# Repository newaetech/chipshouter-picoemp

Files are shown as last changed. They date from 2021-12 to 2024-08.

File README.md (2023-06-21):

# ChipSHOUTER-PicoEMP

[][cc-by-sa]

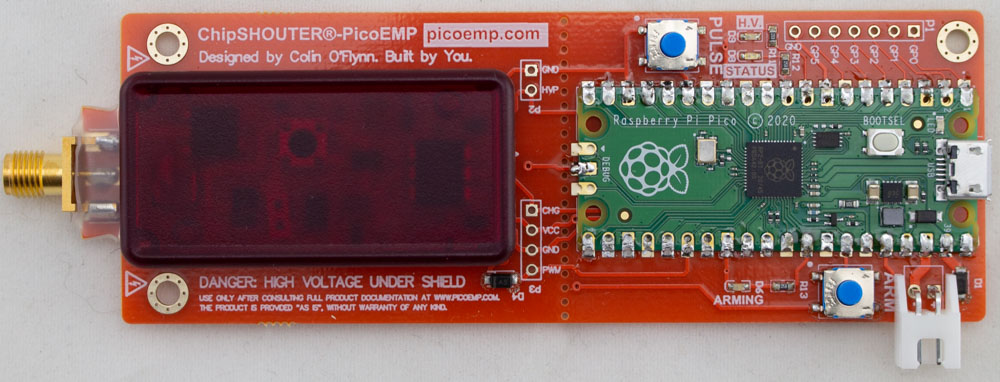
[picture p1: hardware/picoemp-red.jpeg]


The PicoEMP is a low-cost Electromagnetic Fault Injection (EMFI) tool, designed *specifically* for self-study and hobbiest research. Under the safety shield it looks like this:

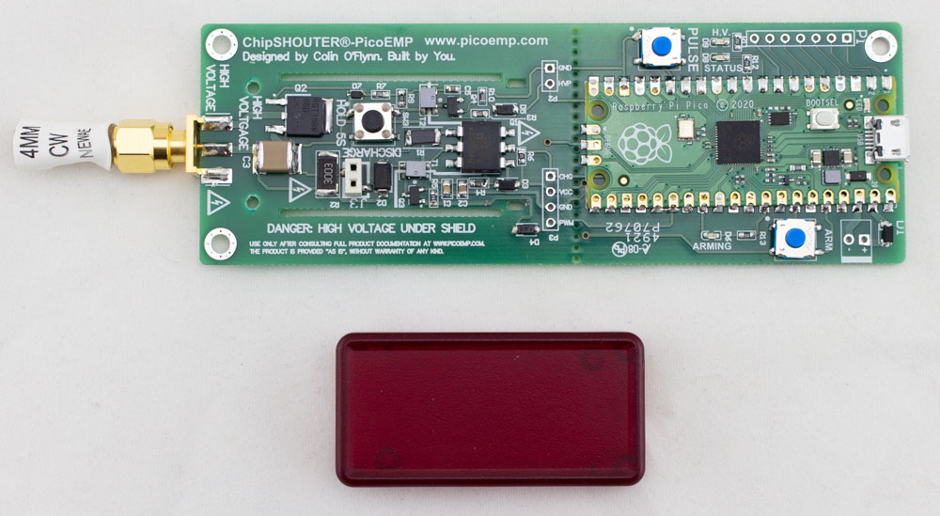
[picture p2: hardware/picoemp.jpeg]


You can see some details of the design in the [Intro Video](https://www.youtube.com/watch?v=nB5arJi-tVE).

## Thanks / Contributors

PicoEMP is a community-focused project, with major contributions from:
* Colin O'Flynn (original HW design, simple Python demo)
* [stacksmashing](https://twitter.com/ghidraninja) (C firmware for full PIO feature-set)
* [Lennert Wouters](https://twitter.com/LennertWo) (C improvements, first real demo)
* [@nilswiersma](https://github.com/nilswiersma) (Triggering/C improvements)

## Background

The [ChipSHOUTER](http://www.chipshouter.com) is a high-end Electromagnetic Fault Injection (EMFI) tool designed by Colin
at [NewAE Technology](http://www.newae.com). While not the first commercially available EMFI tool, ChipSHOUTER was the first
"easily purchasable" (even if expensive) tool with extensive open documentation. The tool was *not* open-source, but it
did contain a variety of detailed description of the design and architecture in the
[User Manual](https://github.com/newaetech/ChipSHOUTER/tree/master/documentation). The ChipSHOUTER design optimization focused in rough order on (1) safe operation, (2) high performance, (3) usability, and finally (4) cost. This results in a tool that covers many use-cases, but may be overkill (and too costly) for many. In additional, acquiring the safety testing/certification is not cheap, and must be accounted for in the product sale price.

The PicoEMP tries to fill in the gap that ChipSHOUTER leaves at the lower end of the spectrum. This PicoEMP project is *not* the
ChipSHOUTER. Instead it's designed to present a "bare bones" tool that has a design optimization focused in rough order of (1) safe
operation, (2) cost, (3) usability, (4) performance. Despite the focus on safety and low-cost, it works *suprisingly* well. It is also
*not* sold as a complete product - you are responsible for building it, ensuring it meets any relevant safety requirements/certifications,
and we completely disclaim all liability for what happens next. Please **only** use PicoEMP where you are building and controlling it
yourself, with total understanding of the operation and risks. It is *not* designed to be used in professional or educational environments,
where tools are expected to meet safety certifications (ChipSHOUTER was designed for these use-cases).

As an open-source project it also collects inputs from various community members, and welcomes your contributions! It also has various remixes of it, including:

* TODO link to people's remixes.

## Building a PicoEMP

The PicoEMP uses a Raspberry Pi Pico as the controller, inspired by @nezza using it for the debug-n-dump tool. You could alternatively use an Arduino or another microcontroller. You basically just need a few things:

1. PWM output to drive HV transformer.
2. Pulse pin to generate a pulse.
3. Status pin to monitor the HV status.

You have two options for building the PicoEMP: (1) total scratch build, or (2) easy-assemble build.

### Scratch Build

The PCB is *mostly* one layer. Original versions of it were milled on a Bantam PCB mill, and the final 'production' version is designed
to still allow this simple milling process. You can find details in the [gerbers](hardware/gerbers) folder, including Bantam-optimized files
which remove some of the smaller vias (used for the mounting holes), and require you to surface-mount the Raspberry Pi Pico. Here was
'rev3' of the PCB with a few hacked up tests:

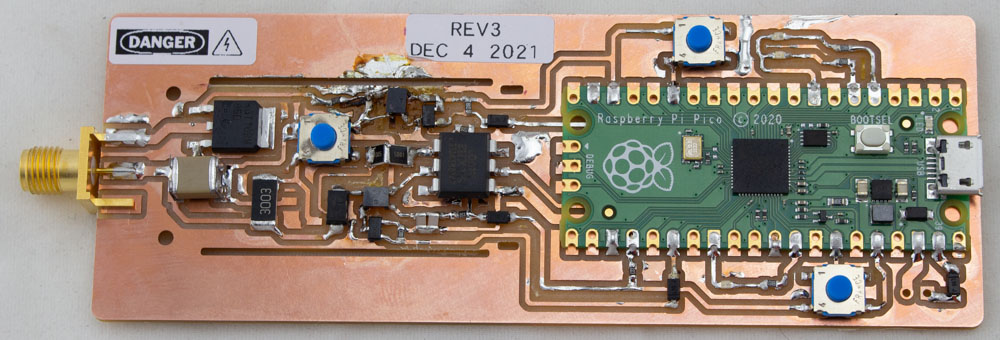
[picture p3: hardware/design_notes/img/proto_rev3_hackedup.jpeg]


If you've got time you can order the "real" PCBs from the [gerbers](hardware/gerbers) as well.

The BOM and build details are described in the [hardware](hardware) folder. If you cannot find the plastic shield (the upper half of Hammond
1551BTRD is used), you can find a simple 3D-printable shield as well. The official shield is low-cost and available from Digikey/Mouser/
Newark so you can purchase alongside everything else you need.

**IMPORTANT**: The plastic shield is critical for safe operation. While the output itself is isolated from the input connections, you will still **easily shock yourself** on the exposed high-voltage capacitor and circuitry. **NEVER** operate the device without the shield.

### Easy-Assemble Build

The Easy-Assembly build uses a "mostly complete" SMD board, which you need to solder a Raspberry Pi Pico, switches, and through-hole headers. Currently it's available only on the [NewAE Store](https://store.newae.com/chipshouter-picoemp). We're working to
get this listed on Mouser for much cheaper worldwide shipping (the NewAE store doesn't get great rates & due to issues with Canada's postal system for international shipments quotes mostly via DHL).

### Programming the PicoEMP

You'll need to program the PicoEMP with the firmware in the [firmware](firmware) directory. You can run other tasks on the microcontroller
as well.

### Building the EM Injection Tip (Probe / Coil)

You will also need an "injection tip", typically made with a ferrite core and some wires wrapped around it. You can see examples of such cores in the ChipSHOUTER kit. The following shows a few homemade & commercial tips:

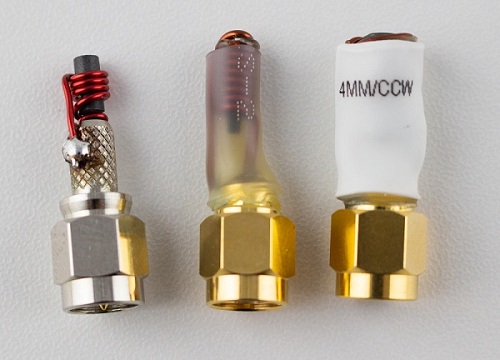
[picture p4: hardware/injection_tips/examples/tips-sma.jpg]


You can make your own from suitable SMA connectors, magnet wire, and a ferrite core material. See the [injection_tips](hardware/injection_tips)
folder for more examples and details on building the probes.

*Reader Note: Please submit your own examples with a pull-request to this repo, it would be great to have more examples of probe geometries*

You can find additional examples of homemade cores in research papers such as:

* A. Cui, R. Housley, "BADFET: Defeating Modern Secure Boot Using Second-Order Pulsed Electromagnetic Fault Injection," USENIX Workshop on Offensive Technologies (WOOT 17), 2017.  [Paper Link.](https://www.usenix.org/conference/woot17/workshop-program/presentation/cui) [Slides Link.](https://github.com/RedBalloonShenanigans/BADFET)
* J. Balasch, D. Arumí and S. Manich, "Design and validation of a platform for electromagnetic fault injection," 2017 32nd Conference on Design of Circuits and Integrated Systems (DCIS), 2017, pp. 1-6. [Paper Link.](https://upcommons.upc.edu/bitstream/handle/2117/116688/bare_conf.pdf)
* J. Toulemont, G. Chancel, J. M. Galliere, F. Mailly, P. Nouet and P. Maurine, "On the scaling of EMFI probes," 2021 Workshop on Fault Detection and Tolerance in Cryptography (FDTC), 2021. [Paper Link.](https://ieeexplore.ieee.org/abstract/document/9565575) [Slides Link.](https://jaif.io/2021/media/JAIF2021%20-%20Toulemont.pdf)
* LimitedResults. "Enter the Gecko," 2021. [Blog Link](https://limitedresults.com/2021/06/enter-the-efm32-gecko/)
* C. Gaine, J-P. Nikolovski, D. Aboulkassimi, J-M. Dutertre. "New probe design for hardware characterization by ElectroMagnetic Fault Injection," EMC Europe 2022 [Paper Link.] (https://hal-cea.archives-ouvertes.fr/cea-03657852/file/article_archivesouvertes.pdf)
* 
### Useful References

If you don't know where to start with FI, you may find a couple chapters of the [Hardware Hacking Handbook](https://nostarch.com/hardwarehacking) useful.

You can see a demo of PicoEMP being used on a real attack in this [TI CC SimpleLink attack demo](https://github.com/KULeuven-COSIC/SimpleLink-FI/blob/main/notebooks/5_ChipSHOUTER-PicoEMP.ipynb).

## Using the PicoEMP

The general usage of the PicoEMP is as follows:

1. Press the "ARM" button. The red "ARMING" led will come on instantly telling you it's trying to charge the high voltage.
2. The red "HV" led will come on after a few seconds saying it is charged to "some voltage".
3. Place the probe tip overtop of the target.
4. Press the "Pulse" button.

You can see more examples of this in the [Intro Video](https://www.youtube.com/watch?v=nB5arJi-tVE).

You can even use the Raspberry Pi Pico to attack a Raspberry Pi "regular"! Here's a demo hitting a RSA signature on a Raspberry Pi (the demo code taken from Colin's [Remoticon 2021 Talk](https://github.com/colinoflynn/remoticon-2021-levelup-hardware-hacking/tree/master/rpi-glitching)):

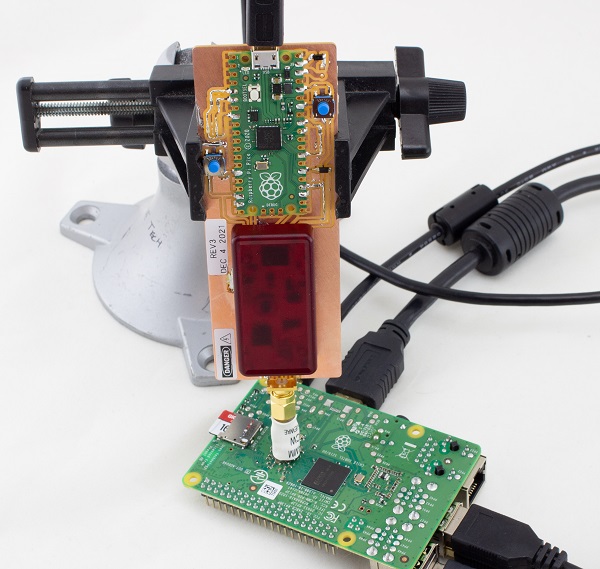
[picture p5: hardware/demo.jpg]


**WARNING**: The high voltage will be applied across the SMA connector. If an injection tip (coil) is present, it will absorb most of the power. If you leave the SMA connector open, you will present a high voltage pulse across this SMA and could shock yourself. Do NOT touch the output SMA tip as a general "best practice", and treat the output as if it has a high voltage present.

The full ChipSHOUTER detects the missing connector tip and refuses to power up the high voltage, the PicoEMP does not have this failsafe!

## About the High Voltage Isolation

Most EMFI tools generate high voltages (similar to a camera flash). Many previous designs of open-source EMFI tools would work well, but [exposed the user to high voltages](https://github.com/RedBalloonShenanigans/BADFET). This was fine provided you use the tool correctly, but of course there is always a risk of grabbing the electrically "hot" tool! This common design choice happens because the easiest way to design an EMFI tool is with "low-side switching" (there is a very short mention of these design choices as well in my [book](https://www.nostarch.com/hardwarehacking) if you are curious). With low-side switching the output connector is always "hot", which presents a serious shock hazard.

PicoEMP gets around this problem by floating the high-voltage side, meaning there is no electrical path between the EMFI probe output and the input voltage ground. With the isolated high voltage output we can use the simple "low-side switching" in a safe manner. Some current will still flow due to the high-frequency spikes, so this isn't *perfect*, but it works well enough in practice (well enough you will shock yourself less often).

The caveat here is for this to work you also need to isolate your gate drive. There are a variety of [solutions to this](https://www.analog.com/en/technical-articles/powering-the-isolated-side-of-your-half-bridge-configuration.html), with the simplist being a gate drive transformer (GDT). The PicoEMP uses the transformer architecture, with some simplifications to further reduce BOM count.

More details of the design are available in the [hardware](hardware) folder.

### Hipot Testing for Validating Isolation

Easy-assemble builds have been subject to a hipot test. This test validates the isolation exists, and has not been compromised by things like leftover flux on the PCB.

This test applies a high voltage (1000V) from the SMA connector pads to the low-voltage signals shorted together. The test is done at 1000V DC, with test passing if LESS than 1 uA of current flows over the 60 seconds test duration. Note this limits is *far* lower than most industry standard limits.

### Technical Differences between ChipSHOUTER and PicoEMP

The main differences from a technical standpoint:

* ChipSHOUTER uses a much more powerful high voltage circuit and transformer (up to ~30W vs ~0.2W) that gives it
  almost unlimited glitch delivery, typically limited by your probe tip. The PicoEMP is slower to recover, typically ~1 to 4 seconds between
  glitches.

* ChipSHOUTER has a larger internal energy storage & more powerful output drivers.

* ChipSHOUTER has a controlled high-voltage setting from 150V to 500V. PicoEMP generates ~250V, there is some feedback but it's uncalibrated.
  **NOTE**: The PicoEMP allows some control of output pulse size by instead controlling the drive signal. This is less reliable (more variability
  in the output), but meets the goal of using the lowest-cost control method.

## License

This work is licensed under a [Creative Commons Attribution-ShareAlike 3.0 International License][cc-by-sa].

[cc-by-sa]: http://creativecommons.org/licenses/by-sa/3.0/
[cc-by-sa-image]: https://licensebuttons.net/l/by-sa/3.0/88x31.png
[cc-by-sa-shield]: https://img.shields.io/badge/License-CC%20BY--SA%203.0-lightgrey.svg

ChipSHOUTER is a trademark of NewAE Technology Inc., registered in the US, European Union, and other jurisdictions.
PicoEMP is a trademark of NewAE Technology Inc.

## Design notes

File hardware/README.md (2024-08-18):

# PicoEMP Build Details

*This page is a (continous) work in progress, original design files in Altium are uploaded*

## BOM

Due to the horribleness that is the 2021 Supply Chain Issues, this "bom explainer" is included and
is split into several parts.
This helps you find alternate parts that you will require because the part we used originally is
not available anywhere.

Part numbers are given in this format (which can be uploaded to e.g., Digi-Key)
```
QUANTITY,PART NUMBER,REF DES
```

Be sure to pick up all parts in the following **4** subsections:

### BOM PART 1: Specific Parts

The following parts are fairly specific and very hard to sub and core to the design:

```
2,ATB322524-0110-T000,T1 T2
1,MM3Z18VB,D7
1,LDA111STR,Q1
1,1551BTRD,SHIELD
1,SC0915,U1
```

NOTES:
* If you can't find ATB322524 basically all is lost. Some distributors just use the `ATB322524` part
number instead of the full one given above, so try the shorter number on Octopart or similar.
* If you can't find MM3Z18VB (D7) try another Zener in ~15V to 20V range. But this diode drastically
affects the drive waveform, so try to avoid subing it.
* The opto LDA111STR is very low-current, and other ones are less likely to work with
the circuit as-is. The feedback isn't "required" per-say so you can omit that circuitry.
* If you can't find `1551BTRD` a 3D printed solution is available, but it will be about
50% less cool-looking.

If you somehow can't get the RPi Pico all is not lost - the pin headers on the board can be driven
with the required signals. If you have another RP2040 board this should be easy, but you could even
drive the signals from an Arduino or similar.

### BOM PART 2: Slightly Generic Parts

The following parts are a little generic, but you try to get the suggested ones if in stock:

```
1,RGT16BM65DTL,Q2
2,AO3422,Q3 Q4
1,TL3301AF160QJ,SW3
1,MURA160T3G,D2
4,SM4005PL-TP,D1 D3 D4 D5
1,KRM55TR72J474MH01K,C3
1,CRMA2010AF20M0FKEF,R1
1,3522300KFT,R2
1,BG306-02-A-2-0400-L-G,J3
1,0732511150,J1
```

KNOWN SUBS:
* D2: US1J-13-F (tested by @gashtaan in [#36](https://github.com/newaetech/chipshouter-picoemp/issues/36), now used in some builds)
* Q3/Q4: PMV37ENEAR
* J1: 142-0701-801

NOTES:
* Q2 is IGBT, 500V+ rating in TO-252 ('DPAK'). Watch a sub here as gate charge may be different which will affect drive
  waveform. In theory you can use a MOSFET instead too (pinout "should" be compatable).
* Q3/Q4 are logic level N-Channel MOSFETs, I use higher voltage rating ones due to potential for inductive kick.
  Watch the gate turn-on voltage, don't just rely on "logic level". Sub a lower Vds rating FET if required.
  *WARNING*: These MOSFETs seem to be surprisingly hard to source sometimes.
* SW3 is a 'discharge' switch and is optional, it should be 5mm high to provide clearance.
* J3 is optional (used for calibrating charge voltage, not used normally).
* D1 D3 D4 D5 are HV diodes for isolation. Suggested ones have 600V rating which is only used in case iolation
breakdown occurs. In circuit they will be exposed to 4V max ever. Almost any diode can be sub'd OK. (NB: The schematic
& old versions of this doc claimed they were Schottky diodes, but as @settinger caught this was never the case).
* C3 is 630V rated, 0.47uF capacitor. Can sub anything in ~0.1uF to 1uF range with same voltage rating & case size
  (watch height! Must be below 5mm to fit shield).
* R1 is 20M-ohm, 2010 size. 1% to 5% is all OK, this part isn't very specific. At least 100mW rating, ideally
  at least 500V rating. Probably will need to change value if you change Q1 (or due to variation of Q1).
* R2 is 300K-ohm, 2510 size. Any value in 120K to 470K is fine. Rated part is 3W which is way overkill, anything 1/4W
  or higher is fine. Dissipation only occurs when you press discharge button.
* J1 is Edge mount SMA. You can sub another connector here or anything else you want (such as screw terminals).

### BOM PART 3: Very Generic Parts

The following parts are not very specific to the design, and you may be better off selecting parts available
at the time. For some of our builds we used existing stock we had that fit the requirements, so there is no
"validated/preferred" part number (unlike Part 1 & Part 2).

```
2,KSC741J LFS,SW1 SW2
2,10R 0603 RESISTOR,R3 R7
1,75R 0805 RESISTOR,R4
5,1K 0603 RESISTOR,R5 R10 R11 R12 R13
1,2K 0805 RESISTOR,R9
1,22K 0603 RESISTOR,R6
2,4.7uF 50V 0805 CERAMIC CAPACITOR,C1 C2
1,100nF 0603 CERAMIC CAPACITOR,C5
2,APT1608SRCPRV,D6 D9
1,APT1608CGCK,D8
```

NOTES:
* SW1 SW2: You can use the same PN as SW3 (the footprint is the same). The suggested switches are kinda
  squishy which I like the feel of more. If you are mounting R-Pi Pico with pins you probably want higher
  switches (like SW3).
* Resistors were 1% in test builds due to our stock, but values not critical. 5% tol is fine.
* C1/C2 were 50V in test builds (50V rating shared with parts from BasicBBI). PicoEMP does not need
  such high rating, but still suggest 25V or higher to avoid biasing voltage reducing effective capacitance.
* C5 was a 50V cap in test builds, but anything > 16V should be fine.
* LEDs: These are just some part numbers we used for one build, but in practice any 0603 red/green LED
  should work.
* You can use 0603 resistors in place of 0805. All prototype builds were done with 0603 to no ill effect.

### BOM PART 4: Other Useful Parts

In practice it's handy having the battery input, which is designed to use the following:

```
1,S2B-XH-A(LF)(SN),J2
1,PRT-09925,BATTERY HOLDER
```

PRT-09925 is a Sparkfun AA battery holder with power switch, terminated in 2.5mm (0.1") JST-XH connector.
This goes right to the R-Pi Pico power input, see the R-Pi Pico documentation for allowed input voltage
ranges.

You will also want some SMA connectors & ferrites to actually use your tool! So pick up for example
at least the following for a minimal-fuss option:
```
1,CONSMA013.062
1,PCV-0-472-03L
1,744710603
```

The SMA connector is to mate with the SMA on the output. You might want to pickup several of them.

Finally you should pick up a USB isolator if you plan on communicating with this thing in operation. There
are lots of these available, but one tested part number you can order from Digi-Key:
```
Seeed Technology Co 114991949
```

Alternatively try `Adafruit 2107`.

### Minimum Build

If you run into supply chain issues, the *absolute minimum parts* needed are:

* Shield (Hammond 1551BTRD)
* T1, T2 (Transformers)
* D2 (High Voltage Rectifier)
* Q2 (High Voltage Switch)
* Q3, Q4 (Low voltage logic-level MOSFET)
* C1, C2 (Caps on HV transformer)
* C3 (Cap on gate drive transformer)
* R3--R7, R9--R13 (various 0603 & 0805 resistors)
* D1, D3--D5 (generic schottky diodes) - they can be replaced with jumpers.
* D7 is *highly recommended* but technically optional, you may immediatly blow up Q2 without it.

This minimum build dumps some features (such as 'charge OK' feedback) and may require more
tuning.

## PCBs

The PCB gerbers can be found in the [gerbers](gerbers) folder. There are two versions:

* Regular Version
* Bantam Mill Version

### Regular Version

The regular gerbers have very little special about them. They should be accepted by your fav
PCB fab (OSHPark, JLCPCB, PCBWay, AllPCB, Advanced Circuits, etc).

The board can be hand-built if you have done a few SMD builds before. The smallest parts are 0603
so there is nothing very crazy. Watch the build order on some parts to make soldering easier:

* Mount J3 (if using) before the nearby SMD parts.
* Mount SW1 & SW2 after mounting R-Pi Pico if SMD mounting the R-Pi Pico.
* Mount Q1 (6-pin optoisolator) after parts around it.

### Bantam Version

The 'bantam mill version' is optimized for milling on a Bantam PCB mill, but could be done with
a classic PCB etch or other PCB mill. It removes most of the throuh-holes from the NC-Drill file
and only includes the copper layers.

This file should work well using both the `0.005" PCB Engraving Bit` and `1/32 end mill` combination.

See the [gerbers/rev04_bantam/README.md](gerbers/rev04_bantam/README.md) file which annotates using this & the required jumper wire!

## Build Process

### PCBA

A assembly drawing is available in the file [BUILD-DRAWING-REV04.PDF](BUILD-DRAWING-REV04.PDF)
which includes the location of parts. Lines indicate the cathods of diodes. The angled ends of
the LEDs indicates their cathods. Some specific notes:

* Watch transformer T1 and T2 have a dot that needs to be matched to the assembly drawing/silkscreen.

* Q1 (6-pin optoisolator) has pin 1 marked on the silkscreen with a line above pin 1 - check this carefully.
  See the photo of assembled boards for a better reference.

* Check D7 cathod carefully - if mounted backwards (or there is an open solder joint on it) you may
  blow up Q2 (the large MOSFET). Depending on your equipment on-hand Q2 may be difficult to replace.

### Shields

The safety shield should "just fit" if the PCB was made correctly with the milled out slots. Use
#2 screws to fit the safety shield - you can cut the ones provided with the Hammond Enclosure in
half with a large pair of side cutters. If your shield doesn't fit, you can use the "other side"
of the Hammond Enclosure (which doesn't have the protrusions) and simply hot glue it to the PCB.

A piece of heat shrink will fit over the connector J1 to ensure only one "pin" is exposed. The
pyramid-like flare on J1 is designed to help the heatshrink fit snugly onto J1.

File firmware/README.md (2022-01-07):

# Firmware

This directory includes the firmware loaded onto the Raspberry Pi Pico.

## C

The C firmware in the [c](c) directory was started by @nezza, and is the most robust/future-proof firmware option!
This includes a serial console similar to ChipSHOUTER, and also allows usage of an external
trigger input.

## Micropython

The micropython firmware is a basic Micropython example. See the [micropython](micropython)
directory for that version and instructions on loading.

This firmware allows only manual usage by the button, and does not include a serial console.

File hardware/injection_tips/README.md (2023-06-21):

# Building Injection Tips

The injection tips are a key part of the usage
of your EMFi tool. This page includes some
examples and tips for when you go to build
your EM tip.

Typically the design of the tips is wire wrapped
around a ferrite core. The core helps
concentrate the magnetic field, up to a factor 2/3, but isn't
required to be present.

## Ferrite Cores

Ferrite cores can be purchased off the shelf
from electronics distributors. You can often
search for "rods" for example. Fair-Rite types 78 and 61 ferrites are well suited and a reference for fault injection. The ferrite diameter is also ideal because it can vary from 750µm to several mm. 

### Shaping Ferrite Cores

Ferrite cores can be shaped with a wet grinding
wheel. These are typically used as knife
sharpeners. The following example one was
purchased from Busy Bee Tools in Canada 
(similar to Harbour Freight in US), part number
CT191:

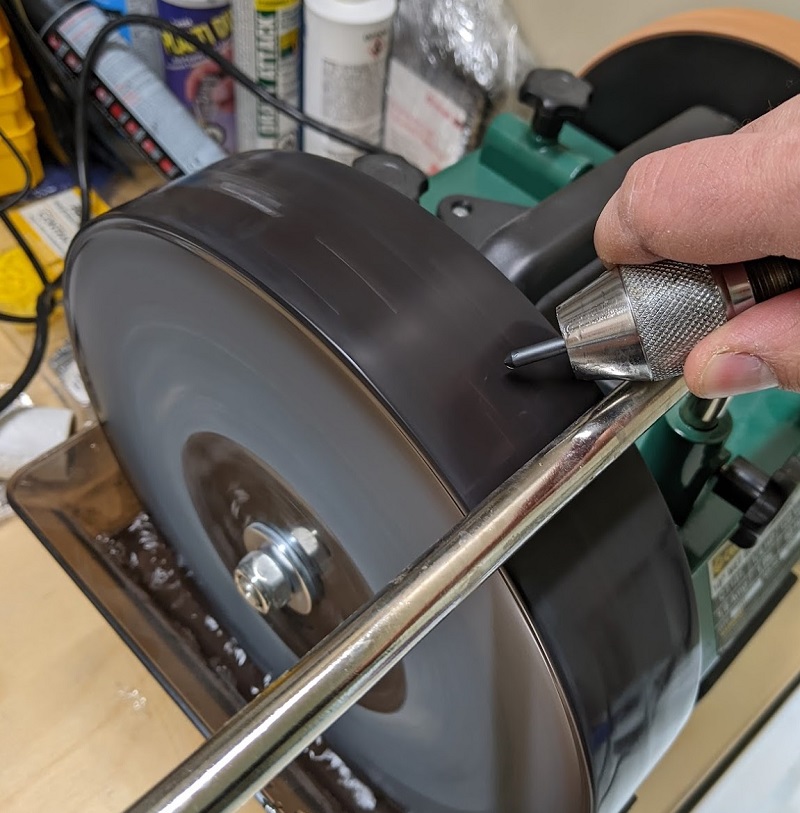
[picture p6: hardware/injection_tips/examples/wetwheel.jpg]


This can be especially useful for shortening
cores. To do this:

1. Cut or break the core with pliers.
2. Use the wet wheel to flaten off the broken end.

## SMA Adapters

Various SMA connectors can be used to adapt to
the SMA connector. For example:

* CONSMA013.062 is used in several examples below. It's an edge-mount male connector.

## Various Examples

### Built Using Inductors

Ferrite-core inductors are common parts, and save you from winding your own coils.

#### Coil Craft

The following was built using `PCV-0-472-03L` inductor. This ferrite has a 'hollow core', but
still seems effective for F-I purposes:

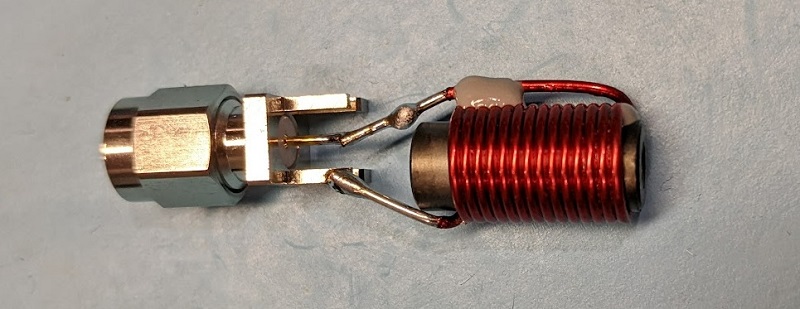
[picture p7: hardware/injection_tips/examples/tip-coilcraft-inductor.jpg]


#### Würth Elektronik

The following is a smaller inductor, Wurth `744710603` (available on Digi-Key):

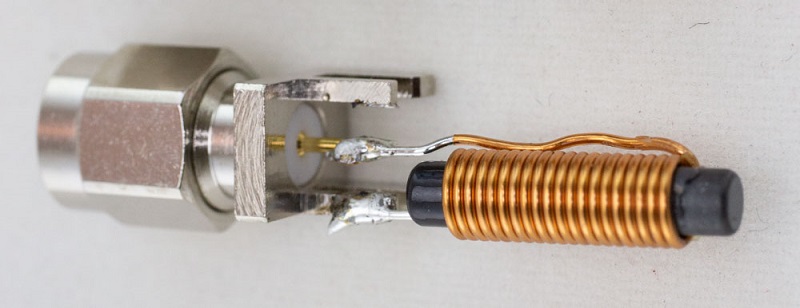
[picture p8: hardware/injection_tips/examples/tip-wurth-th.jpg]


You need to unwind a wrapping to connect to the SMA. I'd consider trying this coil with less windings
as well (unwrap more windings, but keep the windings as close to the 'active' end as possible).

The following shows the Wurth `744710603` shaped, along with a small ferrite toroid (`35T0119-00P`):

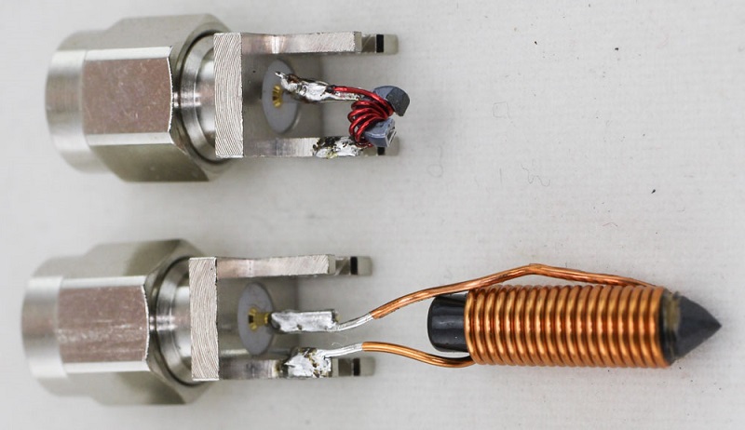
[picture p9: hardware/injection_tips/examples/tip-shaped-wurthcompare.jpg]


Alternatively you can also try experimenting with [radial leaded wire wound inductors](https://www.we-online.com/catalog/en/WE-TI#/articles/WE-TI-6065).
Pictured is a modified `744779068` inductor that has the top ferrite cover and a few windings removed.

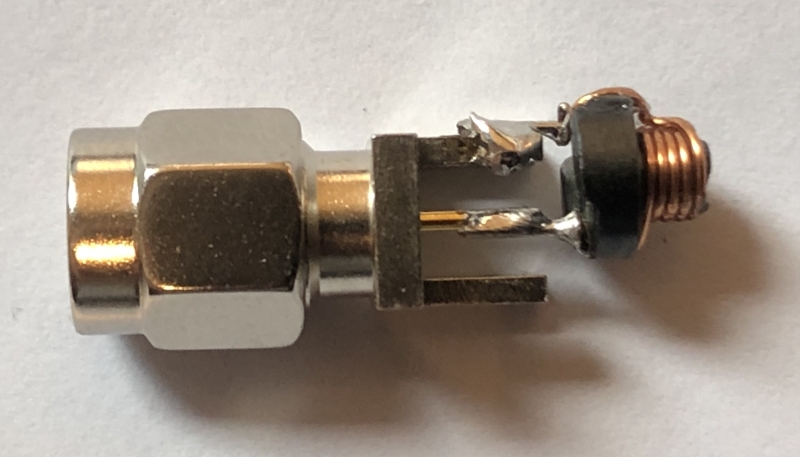
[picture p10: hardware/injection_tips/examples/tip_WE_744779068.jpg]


### Home made probe
#### Conical probe
The following is an example of conical probe with a base diameter of 1.5mm. It is made up of about ten contiguous turns. The average diameter of the probe being 1500µm, it is optimal when the distance with the circuit is 500µm. The ideal is to have a probe radius R=sqrt(2)*z, where z is the distance between the target and the probe. (See "New probe design
for hardware characterization by ElectroMagnetic Fault Injection" by C. Gaine et. al.)
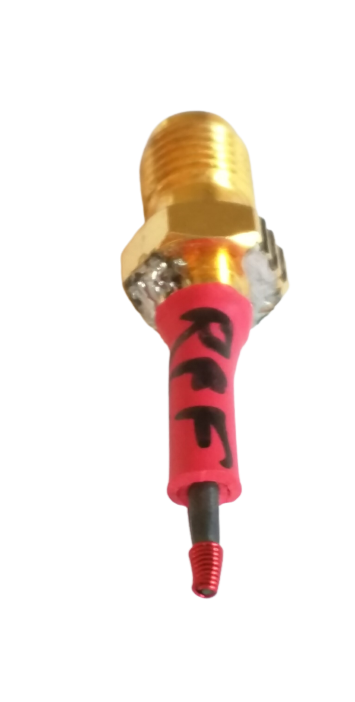
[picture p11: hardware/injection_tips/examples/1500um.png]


#### Precise probe
The following is an example of precise probe with a diameter of 750µmm. It is made up of about 5 contiguous turns, with a diameter of the wire of 40µm. This type of probe can be used where it is necessary to have precise probes, such as SoC.

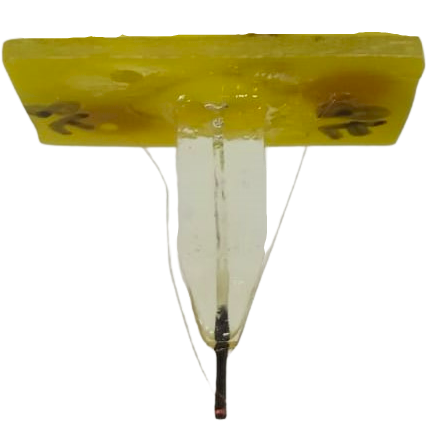
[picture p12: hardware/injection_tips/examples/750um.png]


#### Long slanted ferrite

The following is an example of doing something funky with a ferrite core:
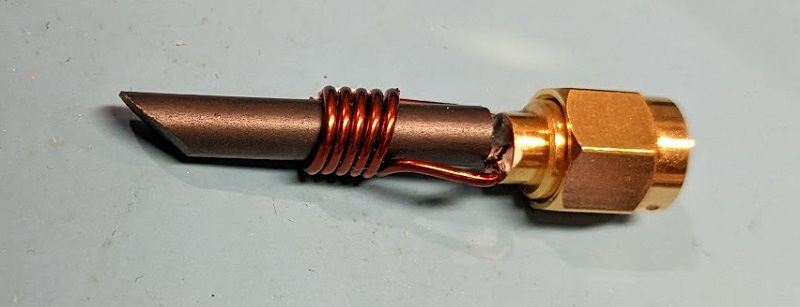
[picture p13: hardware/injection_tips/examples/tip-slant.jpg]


Interestingly note that despite the excessive length of the ferrite, it *still* injects faults.
The strength is lower than with a more sane coil setup, but it shows that the ferrite couples
the energy well.

### Toroid probe
A simple toroid core can be cut in half easily, the following photo shows a roughly cut (with 
side cutters) core. This shows that even without a wet grinder you can still have fun! The
wire used is AWG30 magnet wire.

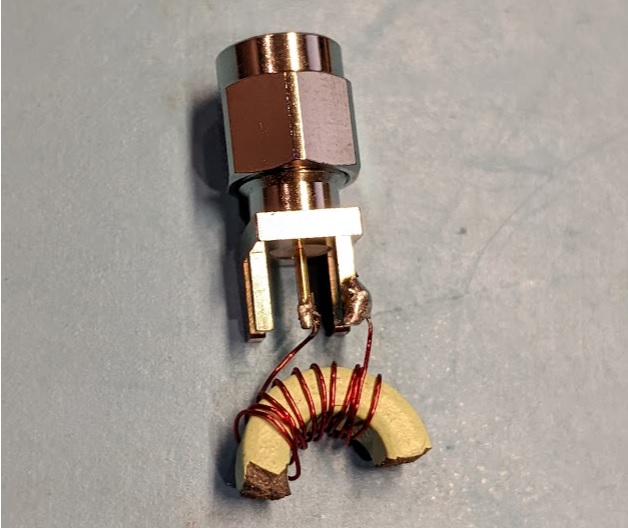
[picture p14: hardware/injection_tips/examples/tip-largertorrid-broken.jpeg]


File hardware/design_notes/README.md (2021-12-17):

# Experimental Notes

## Prototype Builds

## Gate Drive Experiments

The critical part of the design is related to driving the IGBT gate with the correct voltage. Note the turn-on voltage is higher than with a MOSFET,
but we still have the sensitivity to "too high" a gate voltage causing punch-through.

* Proto rev2 "initial": 00000: Gate drive (measured on pins of package), using PDZ10B + 10 ohm series on T2 output. No shunt resistor (R9):

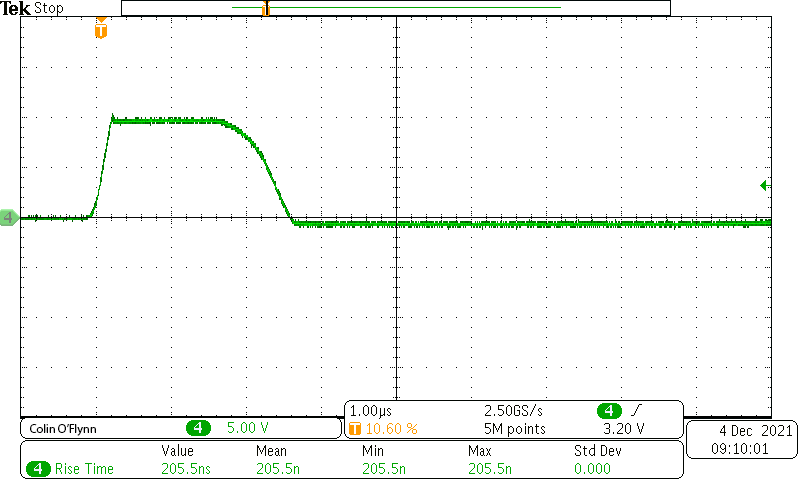
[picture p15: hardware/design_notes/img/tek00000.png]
   

* Proto rev2 "initial": 00001: Output at 4mm coil (across coil) using above drive:

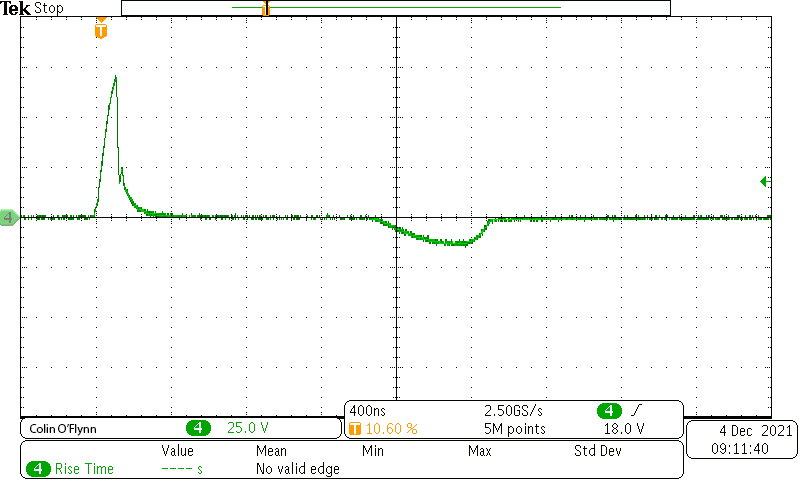
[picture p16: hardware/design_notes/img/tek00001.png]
   

* Proto rev2 "initial": 00002: Output to resistor test jig using above drive:

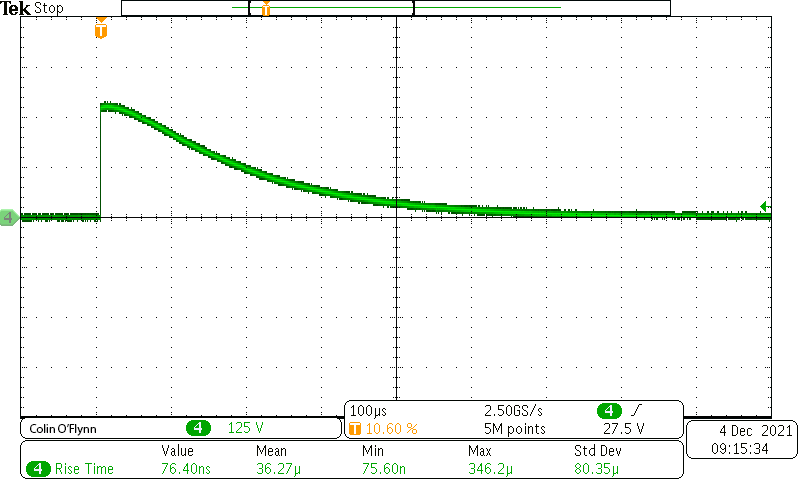
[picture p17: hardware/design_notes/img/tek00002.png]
   

At this point I removed the TVS. I discovered the main "spike" was the wrong polarity, so I swapped the transformer pins with a PCB mod. This swapped
pin orientation is how the rest of the design was done, and I refer to this now as "Proto rev2". This is the same polarity as in the final schematic.
Previously with the diode present it shunted the negative spike so I never saw this issue.

* Proto rev2: 00003: Gate drive (measured on pins of package), using NO TVS (D7), 10 ohm series (R7), 2k shunt resistor (R9):

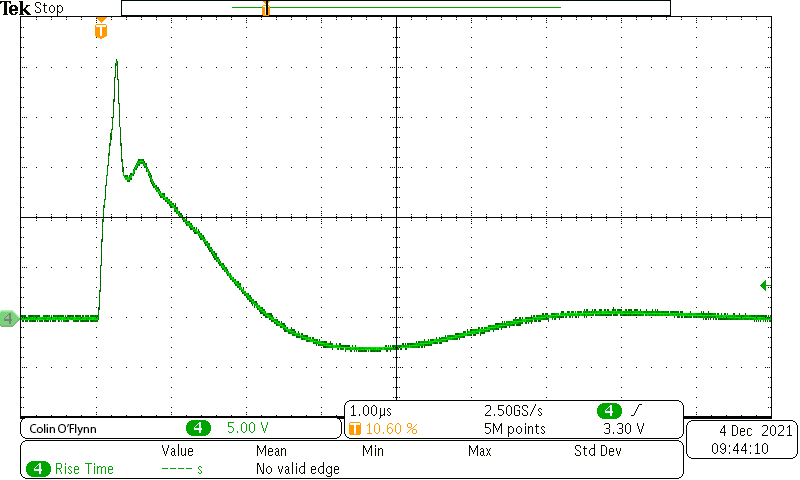
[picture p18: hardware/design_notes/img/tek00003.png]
   

* Proto rev2: 00004: Output to resistor test jig using above drive:

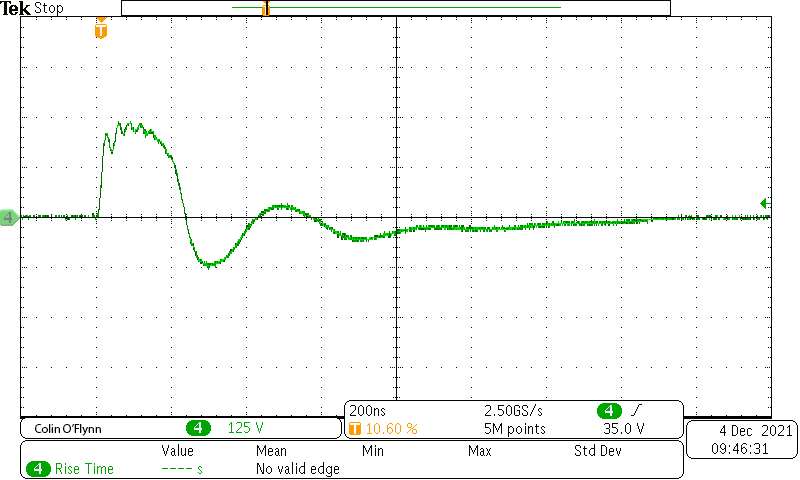
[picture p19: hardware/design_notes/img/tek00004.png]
   

* Proto rev2: 00005: Output to 4mm coil using above drive:

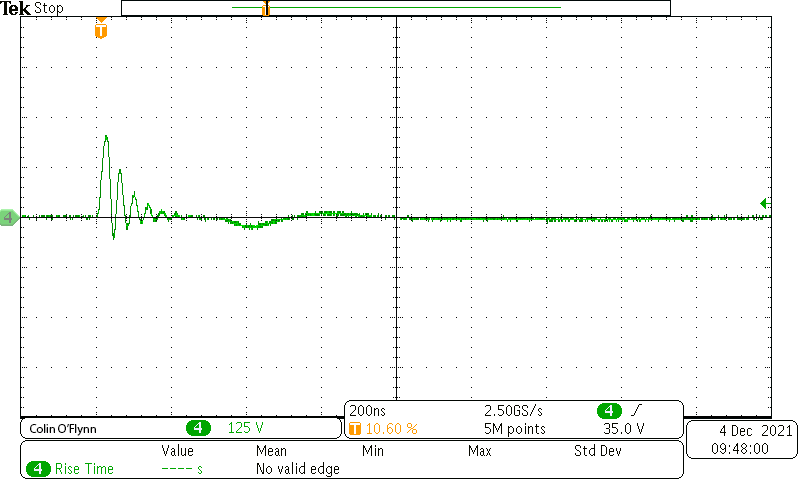
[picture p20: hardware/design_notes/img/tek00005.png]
   

   Note carefully the difference between "00001" - the scales on 00001 are smaller, so you can see a much smaller pulse delivered to the coil. This suggests that
   we've got a winning design here! It also seemed to cause more 'useful' FI effects.

* Proto rev2: 00006: Gate drive (measured on pins of package), using PDZ10B + 10 ohm series on T2 output, 2k shunt resistor (R9):

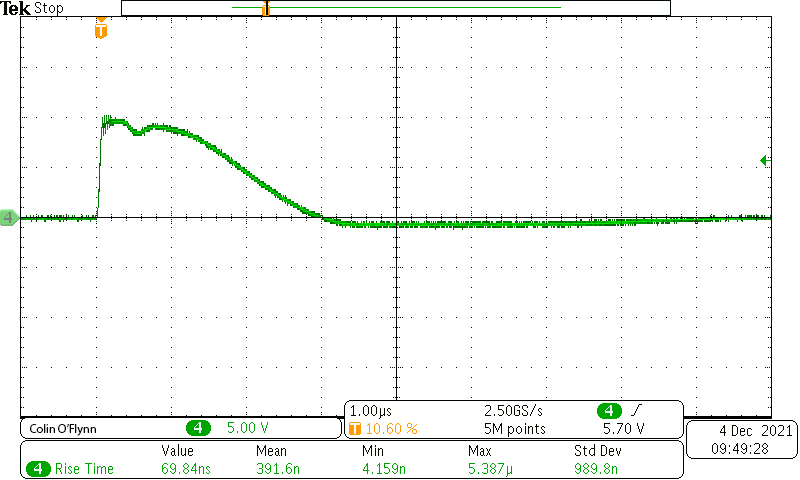
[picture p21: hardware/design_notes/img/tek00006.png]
    

* Proto rev3: 00007/8: Gate drive (measured on pins of package), using 10 ohm series on T2 output, 2k shunt resistor. C5 present (initial build):

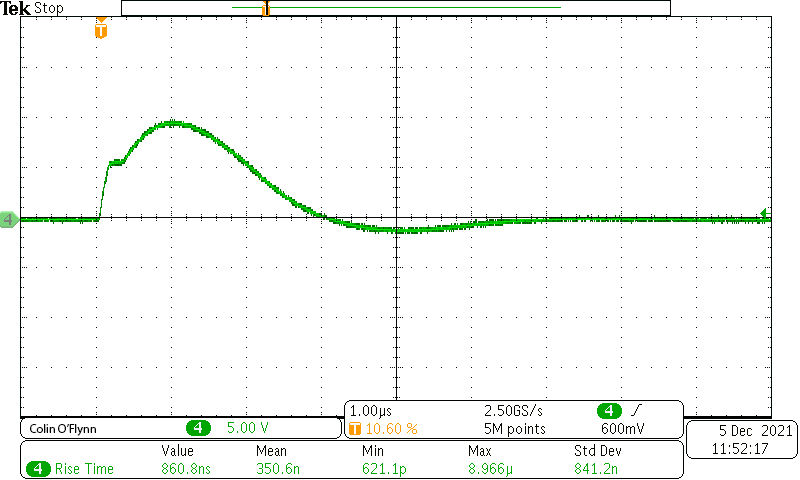
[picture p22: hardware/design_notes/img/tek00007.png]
   

* Proto rev3: 00009: Gate drive (measured on pins of package), using 10 ohm series on T2 output, 10k shunt resistor (R9). C5 missing (100n) - removed for testing:

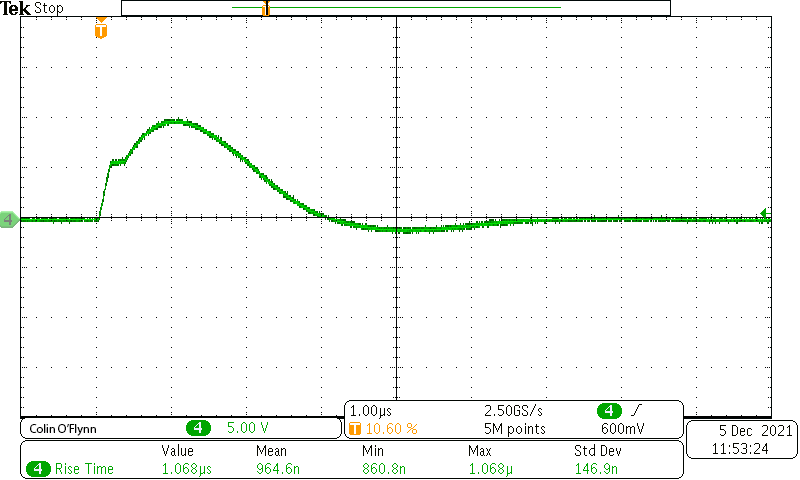
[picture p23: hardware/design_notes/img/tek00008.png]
   

* Proto rev3: 00010: Gate drive (measured on pins of package), using 5 ohm series on T2 output, no shunt. C5 missing (100n):

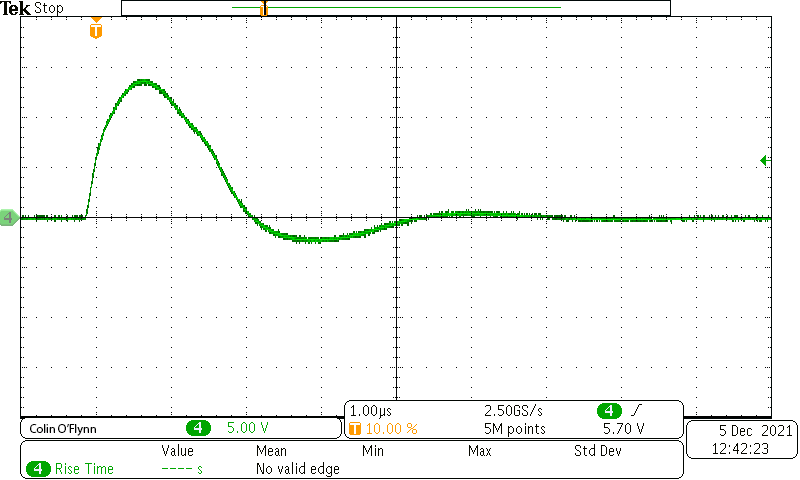
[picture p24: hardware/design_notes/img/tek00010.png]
   

**Proto rev3: Replaced C5. Replaced T2 as pads ripped off (oops).**

* Proto rev3: 00011: Gate drive (measured on pins of package), using 5 ohm series on T2 output, no shunt resistor (R9):

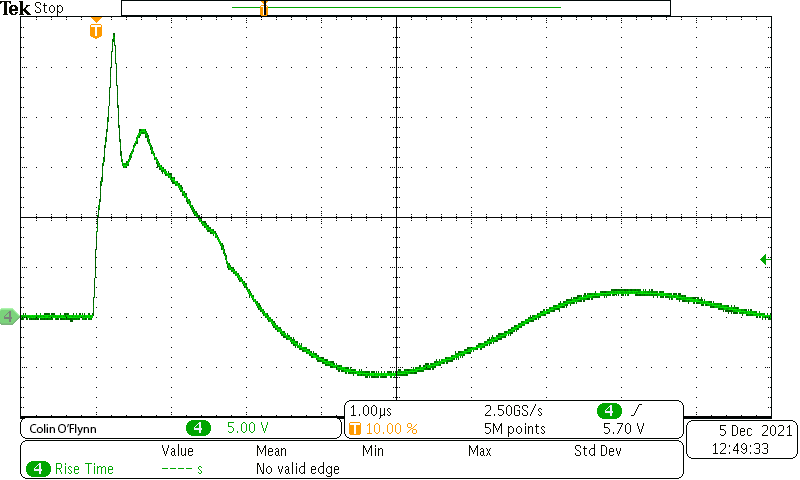
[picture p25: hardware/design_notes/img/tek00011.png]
   

* Proto rev3: 00012: Gate drive (measured on pins of package), using 10 ohm series on T2 output, no shunt resistor (R9):

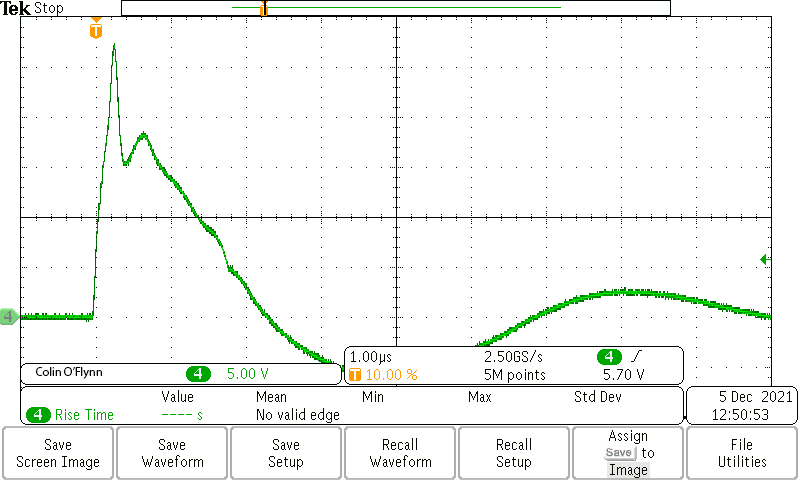
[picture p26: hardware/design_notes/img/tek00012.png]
   

Proto rev3: 00013 - dupe of 12 (saved twice by accident)

* Proto rev3: 00014: Gate drive (measured on pins of package), using 10 ohm series on T2 output, 22k shunt resistor (R9):

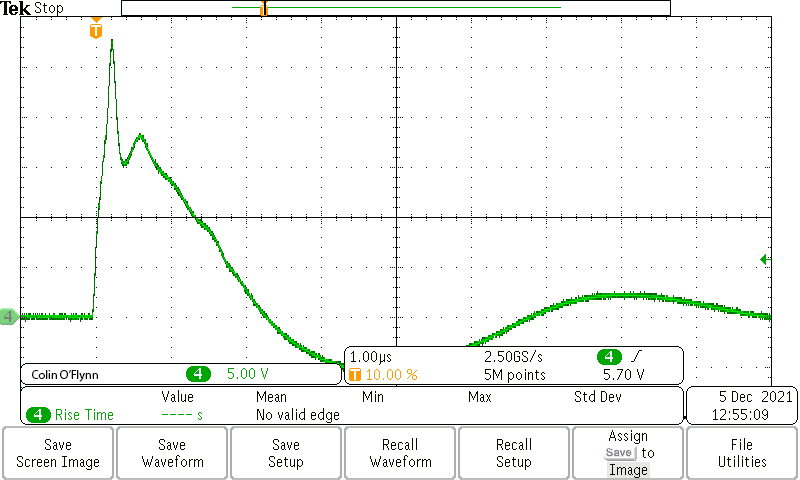
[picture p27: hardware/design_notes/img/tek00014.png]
   

* Proto rev3: 00015: Gate drive (measured on pins of package), using 10 ohm series on T2 output, 2k shunt resistor (R9):
   
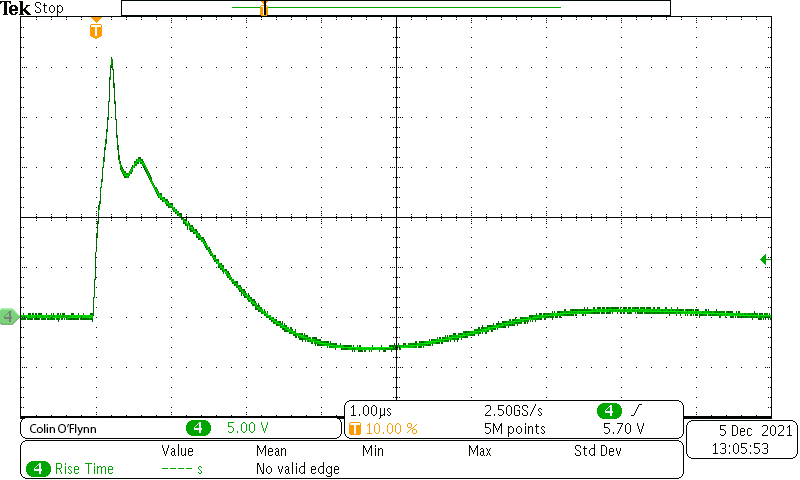
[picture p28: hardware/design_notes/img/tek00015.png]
   

* Proto rev3: 00016 - dupe of 15 (saved twice by accident):

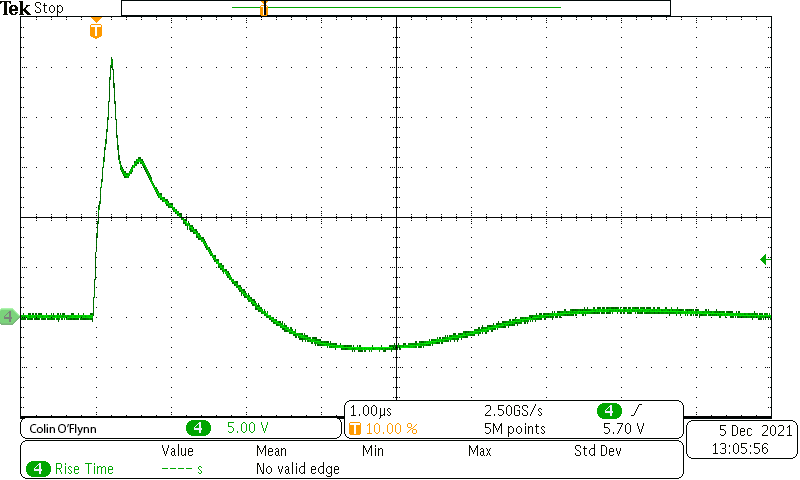
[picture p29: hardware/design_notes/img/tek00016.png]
   

Note the following are performed with "rev2" prototype:

* Proto rev2: 00017: Gate drive (measured on pins of package), using PDZ16BGWJ + 10 ohm series on T2 output, 2k shunt resistor (R9):

   

* Proto rev2: 00018: Gate drive (measured on pins of package), using MM3Z18VB + 10 ohm series on T2 output, 2k shunt resistor (R9):
   
   

This was the "final" selection of parts. MM3Z18VB as Zener/TVS to limit gate voltage, 10 ohm series, 2K shunt. The MM3Z18VB seemed to safely limit
the gate drive in the required speed, so less (no?) chance of gate blowing up.

## Stress Testing

The prototype board was set in a thermal chamber @ 100C for 6 hours, while
continously inserting glitches. It still seemed to work OK after.



A "hi-pot tester" was also used to validate the isolation is reasonable. The
actual isolation is tested at 1kV (well beyond the voltages the device can
generate), and this stress test is applied on any partially assembled units.

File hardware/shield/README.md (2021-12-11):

# Protective Shield

A protective shield is required over the high voltage section of the PCB.

## Hammond 1551BTRD Shield

The shield is based on half of the Hammond 1551BTRD plastic enclosure. This enclosure is translucent red which gives
you the cool looking shield! The following should all fit exactly the same:

* 1551BTRD (Translucent red)
* 1551BCLR (Clear)
* 1551BTSK (Translucent smoke)
* 1551BBK (Black, opaque)
* 1551BGY (Grey, opaque)

The first three give some clear/transparent option.

### Cutting Screws

The provided screws are #2 screws, but are too long for just half of the enclosure. Using a heavy pair of side cutters
(such as ones in the middle of pliers) is sufficient to cut the screws in half.

## 3D Printed Version

A modified version of the Hammond enclosure file is available if you need, which will end up looking like this:



Because of the very low cost of the 1551BTRD Hammond enclosure ($3 and it includes the screws) it is suggested to just buy
the real one! But to ensure you don't get stuck without one due to stock issues, this 3D file is provided. Note the 3D file
is derived from the Hammond enclosure `STP` file, meaning this is *not covered by the open source license*. Use at your
own (legal) risk.

You'll need a set of #2 screws, or just use some hot glue / epoxy to keep the shield attached. The smaller "legs" tend to
not print to the correct size, so you can just cut them off with side cutters if they don't fit into the PCB.

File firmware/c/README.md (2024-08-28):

# PicoEMP C firmware

This is a basic firmware for Colin O'Flynn's [PicoEMP](https://picoemp.com/).

It currently supports:
- Manual arming + pulsing
- Serial interface for arming/disarming/pulsing
- Automatic disarm after 60 seconds
- Fast-trigger via GPIO0 (uses PIO for very fast and consistent triggering)
- External HVP mode: use an external pulse generator (e.g. ChipWhisperer) to control EM pulse insertion

## Serial command documentation:
```
* [h]elp → displays list of commands
* [a]rm → arms device  
* [d]isarm → disarms device
* [p]ulse → sends out single, relatively long pulse of length configured using "c" command (no delay parameter)
* [en]able_timeout → disarms device after certain timeout period
* [di]sable_timeout → disables disarming timeout, i.e. device stays armed unless disarmed manually
* [f]ast_trigger → device triggers when getting a signal on GPIO0, emits pulse of configured length after configured delay
* [fa]st_trigger_configure → sets configuration parameters (# of delay cycles and pulse cycles) for fast_trigger
* [in]ternal_hvp → sets hvp_internal=true
* [ex]ternal_hvp → sets hvp_internal=false
* [c]onfigure → sets pulse power and pulse time (for manual pulse command)
* [t]oggle_gp1 → toggles GPIO pin 1 (not sure what for)
* [s]tatus → print device status
* [r]eset → reboot & reset all settings
```

## Building

```
export PICO_SDK_PATH=.. path to pico SDK ..
cmake -S . -B build
cmake --build build
```

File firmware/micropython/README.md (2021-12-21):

# MicroPython Firmware

## Loading Files

Your raw Raspberry Pi Pico will need to be loaded with:

* MicroPython Interpreter
* The selected file version (below), saved as `main.py` on the R-Pi Pico.

You can find various guides to using the Raspberry Pi Pico. The main steps you need to do are:

1. [Install Thonny](https://projects.raspberrypi.org/en/projects/getting-started-with-the-pico/2)
2. [Install MicroPython Firmware](https://projects.raspberrypi.org/en/projects/getting-started-with-the-pico/3)
3. [Open the selected file and save as `main.py` on the R-Pi Pico](https://projects.raspberrypi.org/en/projects/getting-started-with-the-pico/9)

## Versions

Currently there are the following versions:

* `cspico_simple.py`: Most basic driver example

## `cspico_simple.py`

This version includes only the most basic required functionality. To use this version:

1. Apply power (via MicroUSB or power input).
2. Press 'Arm' switch.
3. Wait for HV light to come on.
4. Press 'pulse' switch.

The default file turns off the high voltage after some time to save battery power. You can comment out this section if you
don't want that:

```
    # Turn off HV if no activity after 60 seconds
    if enabled:
        if utime.ticks_diff(utime.ticks_ms(), timeout_start) > 60000:
            enabled = False
            pwm_off()
            ledArm.off()
```

The default code keeps charging past the 'charged' pin going high. You can improve power consumption by toggling the charging
on/off, but this hurts the already-slow recovery time from pulses being inserted.

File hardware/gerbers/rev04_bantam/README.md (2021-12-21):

# Bantam Optimized Files

## Settings

## Results

The result out of the mill will look something like this:



## Manual Edits

You should remove a bunch of the copper (or increase the settings when you mill):



Watch out for shorts in a few problem areas:



## Jumper

There is one *required* jumper, shown here:



The GND connections will go via the R-Pi Pico, so there is no jumper required, provided you solder all the connected pins on the R-Pi Pico!

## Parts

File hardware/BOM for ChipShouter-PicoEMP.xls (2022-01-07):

Line # | Name | Description | Designator | Quantity | Manufacturer 1 | Manufacturer Part Number 1 | Supplier 1 | Supplier Part Number 1 | Alternate 2
 | Plastic Shield | Plastic Shield |  | 1 | Hammond Manufacturing | 1551BTRD | Digi-Key | HM1624-ND
 | 4.7uF/50V | 4u7, 50V, 0805, Ceramic | C1, C2 | 2 | TDK | C2012X5R1H475K125AB | Digi-Key | 445-5980-1-ND
 | 0.47uF,630V,X7T | 0.47uF, 630V, X7T, Stacked | C3 | 1 | Murata | KRM55TR72J474MH01K | Digi-Key | 490-16845-1-ND | CGA9P1X7T2J474K250KE
 | 100n | 100n, 0603 | C5 | 1 | KEMET | C0603C104K5RACTU | Digi-Key | 399-5089-2-ND
 | SM4005PL-TP |  | D1, D3, D4, D5 | 4 | MCC | SM4005PL-TP | Digi-Key | SM4005PL-TPMSCT-ND
 | MURA160T3G | 600V, 1A, Fast Recovery Diode | D2 | 1 | ON Semiconductor | MURA160T3G |  |  | US1J-13-F
 | LED, 0603, Red | Chip LED, Red | D6, D9 | 2 | Kingbright | APT1608SRCPRV | Digi-Key | 754-1122-1-ND
 | MM3Z18VB |  | D7 | 1 | ON Semiconductor / Fairchild | MM3Z18VB | Digi-Key | MM3Z18VBCT-ND
 | LED, 0603, Green | Chip LED, Green | D8 | 1 | Kingbright | APT1608CGCK | Digi-Key | 754-1116-1-ND
 | EDGE-SMA | Edge-Mount SMA, 0.062" PCB | J1 | 1 | Molex | 732511150 | Digi-Key |  | 142-0701-801
 | 1x2_Pin_Header | JST XH 0.1" HEADER | J2 | 1 | JST | S2B-XH-A(LF)(SN) | Digi-Key | 455-2257-ND
 | BG306-02-A-2-0400-L-G | 2-Pin SMD, Female Header, 0.1" spacing | J3 | 1 | Global Connector Technology | BG306-02-A-2-0400-L-G | Newark | 07W6674
 | LDA111STR | Phototransistor | Q1 | 1 | Ixys Clare | LDA111STR | Digi-Key | 212-LDA111SCT-ND
 | RGT16BM65DTL | IGBT 650V | Q2 | 1 | Rohm | RGT16BM65DTL | Mouser | 755-RGT16BM65DTL
 | AO3422 | MOSFET N-CH 30V 2.2A SOT23-3 | Q3, Q4 | 2 |  | AO3422 |  |  | PMV37ENEAR
 | 20M | 20M, 2010, 1% | R1 | 1 |  | CRMA2010AF20M0FKEF | Digi-Key
 | 300K | 300K res, 2512, 1%, 3W | R2 | 1 | TE Connectivity CGS | 3522300KFT | Digi-Key | A121215CT-ND
 | 10R | 10R res, 0603, 1%, 1/10W | R3, R7 | 2 | Yageo | RC0603FR-0710RL | Digi-Key | 311-10.0HRCT-ND
 | 75R | 75R res, 0805, 1%, 1/8W | R4 | 1 | Yageo | RC0805FR-0775RL | Digi-Key | 311-75.0CRCT-ND
 | 1k | 1k res, 0603, 1%, 1/10W | R5, R10, R11, R12, R13 | 5 | Yageo | RC0603FR-071KL | Digi-Key | 311-1.00KHRCT-ND
 | 22k | 22k res, 0603, 1%, 1/10W | R6 | 1 | Yageo | RC0603FR-0722KL | Digi-Key | 311-22.0KHRCT-ND
 | 2k | 2k, 0805, 1%, 1/8W | R9 | 1 | Yageo | RC0805FR-072KL | Digi-Key | 311-2.00KCRCT-ND
 | KSC741J LFS | SWITCH TACTILE SPST-NO 0.01A 32V | SW1, SW2 | 2 | ITT C&K | KSC741JLFS | Digi-Key | CKN10309CT-ND
 | TL3301AF160QJ | SWITCH TACTILE SPST-NO 0.01A 32V | SW3 | 1 | E-Switch | TL3301AF160QJ
 | ATB322524 | HV Transformer 1:10, Small | T1, T2 | 2 | TDK | ATB322524-0110-T000 | Digi-Key | 445-8636-1-ND
 | SC0915 | Raspberry Pi Pico | U1 | 1 | Raspberry Pi | SC0915
 | PRT-09925 | Battery Holder, 2xAA, with Switch | BH1 | 1 | Sparkfun Electronics | PRT-09925
 | Probe: SMA | For Example Probe |  | 1 |  | CONSMA013.062
 | Probe: Inductor | For Example Probe |  | 1 |  | PCV-0-472-03L

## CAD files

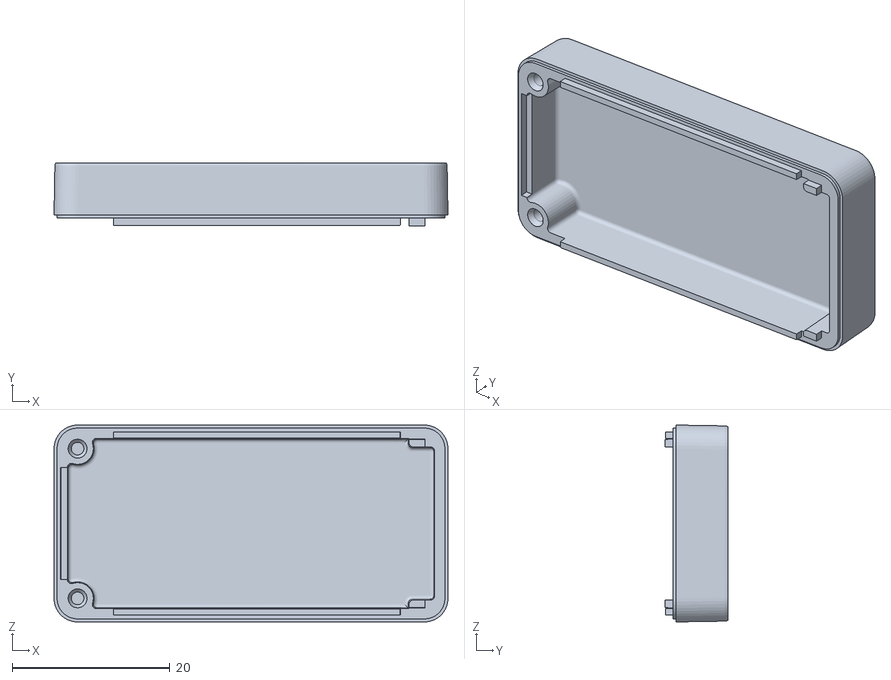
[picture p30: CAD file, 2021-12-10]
hardware/shield/picoempshield-1551BTRD-top.stl
50.0 x 8.00 x 25.0

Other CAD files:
hardware/shield/picoempshield-1551BTRD-top.f3d

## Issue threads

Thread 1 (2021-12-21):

Kit / Easy-Assemble Build Availability

colinoflynn, 2021-12-21:
One goal is to eventually offer a "partial kit", which will be in $50 to $100 range most likely. This kit would require you to solder the R-Pi Pico & some switches onto the board, but the SMD part would be **done**. This board would also be hi-pot + functionally tested,

*NOTE: A "full assembly" kit is probably never going to be offered, as the cost of kitting the SMD parts would be more than the cost of the SMD run. SMD kits have a higher failure rate which adds considerable "average support costs" ontop. Due to the availability of very low cost PCB services like JLCPCB or OSHPARK if you want a full kit please order the PCB & parts directly.*

gmgunderground, 2021-12-22:
Well done, I will wait for it!

SoftwareEngineer, 2021-12-22:
Nice! Very interested in a "partial kit". Will it be possible to put a header on the board instead of soldering the R-Pi pico right on the board?

david-oswald, 2021-12-23:
Definitely interested in 1-2 of them.

inode-, 2021-12-23:
Waiting for it!

grymoire, 2021-12-24:
Put me down for a maybe.

matthew5025, 2021-12-25:
+1 would be interested too!

m-ober, 2021-12-26:
Count me in.

jcldf, 2021-12-26:
yeah! I'm interested

avloginov, 2021-12-26:
I'd be happy to buy either easy to assemble or just empty board.

osok, 2021-12-28:
I am interested

FlUxIuS, 2021-12-29:
Would be happy to test the easy-assemble build!
Thanks in advance!

doegox, 2021-12-30:
Yup, I'm interested by the easy-assemble kit too :)

jonahedwards, 2022-01-03:
Definitely interested!

RobinFassina-Moschini, 2022-01-05:
Interested by the easy-assemble kit too.

KypForty, 2022-01-07:
Interested by mostly complete SMD board. Regards!

jslawek, 2022-01-13:
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

gohai, 2022-01-16:
Interested in partial kit

AlexanderKrampe, 2022-01-17:
Interested +1

shinmai, 2022-01-18:
+1 for sure

LovelyA72, 2022-01-18:
Sign me up!

gworona, 2022-01-20:
Interested

Gabbo28, 2022-01-21:
Interested!

max-r-b, 2022-01-25:
Interested as well! Thanks!

hexsecs, 2022-01-25:
Definitely interested!

jamesy0ung, 2022-02-12:
+1

Xenador77, 2022-02-28:
Interested as a southerner in a colloquialism

hgordon-git, 2022-03-08:
super interested. I would get one to three.

pr0z78, 2022-03-15:
Yes hyped and interested for at least 2 (shared buy for co-worker) or 3 (also 1 for team) when it  becomes available.

afflitto, 2022-04-05:
very interested!

zommiommy, 2022-04-14:
+1

steelfly33, 2022-04-28:
+1

colinoflynn, 2022-05-30:
Thanks for the patience all - we've released our first run of the kit at https://store.newae.com/chipshouter-picoemp . If you'll be at RECON in Montreal we have a special discount - free shipping if you pick up in person (use code RECON). Note the following:

* Requires 2xAA batteries for use (excluded as we weren't sure if it caused shipping issues, it looks like maybe not but we hadn't ordered them for the kit builds so we don't want to delay on that)
* We ship via DHL - we cannot ship via mail as historically the service is very unreliable & it's not worthwhile for us. This makes the shipping cost a large % of the unit cost - you can save a bit by splitting shipping, 4 fit in our smallest box.

We'll eventually see if there is easier ways to stock this - but for now in this initial run the logistics are likely going to be a bit heavy!

autoprog, 2022-11-14:
Hi,
in Moser not have https://store.newae.com/chipshouter-picoemp
Do you ship to Brazil?,
thanks,
Carlos.

mrx23dot, 2024-02-27:
Any update on availability? What about selling on Tindie or Sparkfun, I think they fullfil orders.

eried, 2024-08-27:
:) still no mouser? :/

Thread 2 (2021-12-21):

Python Interface?

colinoflynn, 2021-12-21:
Currently the simple micropython is button driven. Would be good to add a way of interacting from a computer with the board (with caveat it's "officially not recommended" to run board from computer without isolation).

lukaskuzmiak, 2021-12-23:
Hopefully not too unrelated - would you say it is a good idea run the board from the computer using a USB isolator of some sort? If you think so, maybe mention that when you end up making the interface.

At least from my point of view, I'd be happy to consider the PicoEMP and any other HW to interface with target technically as sacrificial but I'd want that strongly isolated from other (possibly a lot more expensive) equipment.

colinoflynn, 2021-12-23:
Depends how expensive your computer is ;-) I'm wondering about that side too.. using a different RP2040 board would let me add a USB isolator chip, but otherwise/for now I'd guess something like https://www.adafruit.com/product/2107 would be a good starting point. I've even seen cheaper versions (like https://www.aliexpress.com/item/4000047053305.html) that are total no-brainers! Maybe I'll add that note into the usage for now at least.

To be honest I'm running the thing directly plugged into my 1-month-old laptop, so it "should" be fairly safe (the DC-DC transformers are rated 500Vrms isolation, and the charge normally goes only to 250V DC).

But of course besides part failure, if you had a solder ball or something left over by accident it would also kill the isolation! So adding the $10 to $40 isolator cost is well worth it for anyone running from a computer.

mattytrentini, 2022-10-22:
Since the Pico W has been released - and it's pin-compatible - it would be possible to use wifi (or BLE, soon) to trigger the glitch....

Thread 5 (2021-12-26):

Part Substitutions

colinoflynn, 2021-12-26:
Using this issue to track potential subs for problematic parts.

colinoflynn, 2021-12-26:
For Q3/Q4 - big important point is that it's fully "on" by 3V. There is a Schottky diode drop on the gate drive so you've got to be careful there. Check the Vgs figure for any sub - here is the "original" AO3422:

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

Then the PMV37ENEA (this was used in current builds):

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

The specific Rds isn't too important, mostly that it's "on" by that point. I've noticed some logic-level MOSFETs are only starting to turn on around 3V, so you'll see that curve shifted to the right a little more than I'd like. I haven't done much testing here so it *may* not be too critical, but if you want to avoid potential issues I'd just check the Vgs curve for anything you find in stock (along with footprints).

osok, 2022-01-02:
Where can we get the probe tips?  Is there a good resource for making them?

colinoflynn, 2022-01-02:
@osok There is a lot of experimentation needed there IMO. But you'll find some examples in https://github.com/newaetech/chipshouter-picoemp/tree/main/hardware/injection_tips for now. There are more resources "out there" (other papers) I'm figuring out best way to link, there were a few linked from the main README as well.

nilswiersma, 2022-02-05:
Is there any specific upside to having C3 being multilayered? Or as long as uF and V and height is as you mentioned in README, should be good?

colinoflynn, 2022-02-06:
By multilayered you mean the part number which has the two thin devices stacked? I wouldn't worry about that specifically. You could compare ESR/ESL specs and similar too, but for the most part I think any ceramic device is going to be good enough for picoemp usage!

PoroCYon, 2022-02-28:
I've used a SQ2364EES-T1_GE3 as replacement for Q4. Ron is a bit higher and the threshold voltage is a bit lower, but it seems to work. Sadly by now they seem to be out of stock as well.

colinoflynn, 2022-02-28:
Thanks for dropping the note still! At least good to know what sort of "range" is doable with these things (and maybe it comes back in stock later?)

gmgunderground, 2022-04-03:
Hi, no one of the C3 codes are available on Mouser, does
[CGA9P1X7T2J474M250KC](https://www.mouser.it/ProductDetail/TDK/CGA9P1X7T2J474M250KC?qs=xLDY6iXSiQaSRDUMzY513g%3D%3D)
[CKG57NX7R2J474M500JH](https://www.mouser.it/ProductDetail/TDK/CKG57NX7R2J474M500JH?qs=NRhsANhppD%252BAmXDR5rVERg%3D%3D)
[CKG57KX7T2J474K335JH](https://www.mouser.it/ProductDetail/TDK/CKG57KX7T2J474K335JH?qs=xLDY6iXSiQaxAZWnHJ3xxg%3D%3D)
[C5750X7T2J474M250KE](https://www.mouser.it/ProductDetail/TDK/C5750X7T2J474M250KE?qs=LcTL%2F5vFEzGH3h7%252BwrjxaQ%3D%3D)
Are valid alternatives?
These appear to be available on Mouser at the moment

colinoflynn, 2022-04-03:
They should work I think! You can double-check the size dimensions for footprint, but they look reasonable. The original part was a bit of a random pick (at the time lots of stock) so wasn't anything besides voltage/cap/case that I matched.

LennertW, 2022-04-03:
CKG57KX7T2J474K335JH worked for me!

gmgunderground, 2022-04-03:
Perfect, thank you very much

Il dom 3 apr 2022, 22:16 LennertW ***@***.***> ha scritto:

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

gmgunderground, 2022-05-03:
It's becoming difficult to find all the components.
I can't find RGT16BM65DTL on Mouser, is ok to substitute with IKD15N60RATMA1? Otherwise any suggestion?
Also AO3422 and alternative PMV37ENEAR are still unavailable on Moser and Digikey, what can I use as an alternative (best available on Mouser)?

gmgunderground, 2022-05-30:
Can RGPZ10BM40FHTL or IKD15N60RC2ATMA1 be a valid substitute for Q2 (RGT16BM65DTL) ? On Digikey is the only component I can't find.
What can I use? Mouser and Digikey doesn't have RGT16BM65DTL.
PCV-0-472-03L is missing too (Coil).

colinoflynn, 2022-05-31:
The coil isn't critical - in fact we ended up providing a different PN in the kit, we used Wurth 744710603. Check the `hardware/injection_tips` for some details of that.

I'd think any of these IGBTs would work ok! There wasn't anything too magic about that, mostly just the voltage rating (current too, but as the current is only a short pulse so not as critical). I think my specs for both are way overkill, so yours should be fine!

settinger, 2022-08-21:
In the Build Details page, D1 D3 D4 D5 are described as Schottky diodes, and they are depicted as such in the schematic, but SM4005PL-TP appears to be a general purpose diode. I don't see any reason why SM4005PL-TP *wouldn't* work, but figured I should point out the discrepancy. Really looking forward to building this, thank you!

colinoflynn, 2022-08-21:
Oops, thanks @settinger! Probably just when first doing the design planned on using them, but then never actually did. I'll remove that so it's not confusing people on the hunt for other parts.

colinoflynn, 2022-12-11:
FYI I tested @gmgunderground's suggested sub on Q2, IKD15N60RC2ATMA1. Seems to work, and pulse looks similar - Yellow is RGT16BM65DTL, Blue is IKD15N60RC2ATMA1. Will update the BOM as well since we're likely to use this in a few runs due to using all of our own horded stock of RGT16BM65DTL now.
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

gmgunderground, 2024-07-03:
R1 of 20M 1W is not available on Mouser, can the following that is 0.5W suitable too?
https://www.mouser.it/ProductDetail/Vishay-Techno/CRMA2010AF20M0FKEF?qs=1mbolxNpo8frXfdCgvcryg%3D%3D

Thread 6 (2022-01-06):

Clarification on BOM Parts

pk-r7, 2022-01-06:
The BOM identifies D2 as a 600V, 2A fast recovery diode. The part # in the BOM and the alternate are both 1A.
C1 and C2 GRM32ER71H475KA88L refers to a 1210 package cap, not an 0805

colinoflynn, 2022-01-07:
The D2 change is fine (have validated both), I think the 2A was copy-paste error. FWIW the currents (even peak) should be *much* lower as the input primary current is < 1A so the output secondary is going to be mA range. Thanks for fix on C1/C2! Added the PN we use internally for that package (not sure how that happened), it's also in stock at Digikey.

Any preference on BOM file format? I find `.cvs` annoying as it doesn't always import correctly, but the XLS file is hard to view in the repo. I could just use `.cvs` and maybe it's easier for people to catch these.

Closed 2022-01-07.

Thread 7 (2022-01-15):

Aisler: inner milling paths missing and/or incomplete

PoroCYon, 2022-01-15:
When trying to order the board from [Aisler](https://aisler.net/), a warning is shown, saying that the Gerber files don't have some required information on the inner milling paths meant for the shield. As the repository doesn't contain any EDA project files, I can't really fix it myself.

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

([This](https://aisler.net/help/design-rules-and-specifications/plated-and-non-plated-slots-and-cutouts) is the "Design Guidelines" link from the screenshot.)

(Also, would it be possible to have a PCB that conforms to Aisler's "[simple](https://aisler.net/help/design-rules-and-specifications/design-rules)" design rules? This would reduce the cost of ordering one.)

colinoflynn, 2022-01-16:
Unfortunately it's not reasonable to create variants for all the different services out there, the existing gerbers seemed to work with at least several low-cost services tested (oshpark, pcbway, jlcpcb). Not sure where the inner milling error is - it may be this is actually milled as a slot so there is no "closed path", and the error is on their side? I'm planning on pushing the src once the cleanup is done a little more, they are Altium anyway so normally less useful.

hiviah, 2022-01-18:
I ordered from aisler despite those warnings and the boards arrived correctly.
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

invd, 2022-01-30:
My order with Aisler had different results and the inner milling paths on the PCBs **are missing** similarly to the red board variant in the [introduction video](https://www.youtube.com/watch?v=nB5arJi-tVE&t=103s). The mounting holes at the edge of the PCB as well as the two shield mounting holes near the high voltage SMA connector are done correctly.

For people in a similar situation: it is possible to cut away the notches and tabs on the Hammond enclosure and still screw it in place as a high voltage shield via the two remaining mounting holes.

On a related note: the two black screws supplied with the Hammond 1551 case are slightly too large in diameter to go through the mounting holes without biting into the PCB. From what I can tell, it is better not to stress the PCB at that point, so I used smaller screws instead. I'm not sure if this is connected to milling problems, but it's worth thinking about larger diameter mounting holes to avoid this problem in newer revisions.

Closed 2022-01-16.

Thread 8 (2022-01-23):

Rpi pico dead after initial test

mehdideveloper, 2022-01-23:
Hey Colin
I built a PicoEMP today, however I was not sure how to properly test it to make sure everything is working as expected.
I uploaded the C-based firmware, and initially everything seemed to be working (LEDs working. Pushing ARM made D6 turn on, etc)
After a few times pushing the ARM and PULSE buttons, device stopped working (LEDs stayed ON. I reset the device and now LEDs don't turn on. The rpi pico's builtin LED dimly turns on and then off. I think maybe rpi is damaged. Is it possible to actually somehow damage the rpi pico?)
Now if I turn it on and wait a few minutes, the ARMING LED dimly turns on and if I push (and hold) the ARM switch, the LED also gets brighter.
Did you face any similar issues while building your samples? Visually everything seems to be ok. Not sure where to start with spotting the faulty part.

colinoflynn, 2022-01-23:
Not sure! I haven't seen that, I've built several of them without issue. It may be a power supply thing it sounds like, you could try breaking the VCC connection between the rpi and power side? Check those voltages as well perhaps?

mehdideveloper, 2022-01-23:
Thanks. Will double check them.
Just putting here for future reference, if someone searches:
Now, after a few resets, pushing the ARM switch turns the ARMING LED on, but as I leave my finger, the LED also turns off (it's ON as long as I press and hold the switch)
Will post my findings and fixes here.

osok, 2022-01-23:
I had a similar problem after making mine.  I put it under a microscope (cheap video one) and saw that there two places where the solder bridged.  A small wire brush actually worked to fix that problem.

mehdideveloper, 2022-01-24:
Ok, so the Raspberry Pico is dead for whatever reason (too much current draw from its 3V3_OUT?!)
I tried on a new bare PCB, but this time I only assembled the micro-controller side. Now when I connect the microUSB, and push the ARM button, the ARMING LED turns on, but the HV LED does not (which makes sense, as the HV side is not populated yet)
Will build the rest and see how it goes.

Closed 2022-01-29.

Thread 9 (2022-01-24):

Battery holder and pin header compatibility

mehdideveloper, 2022-01-24:
Hey
It seems that either J2 or BH1 are the wrong part number here.
I ordered according to BOM (`S2B-XH-A(LF)(SN)` and `PRT-09925`). They do match, but the polarity is reversed. The VCC on battery holder matches the GND on the pin header/PCB.  The one shown in your Youtube video has the right polarity though.

Please see the attached pictures:

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

Here's yours. Please note the difference:
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

BG7YWL, 2022-01-24:
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

colinoflynn, 2022-01-24:
I think yours is defective - see https://www.sparkfun.com/products/9925 which shows the pinout of mine being the same as in the sparkfun photo.

mehdideveloper, 2022-01-24:
Yes. Digikey is selling the wrong product under Sparkfun PRT-09925. Just reported the error to them.

colinoflynn, 2022-01-24:
Might have been an error in that batch, as I bought it in December and it was the "right" way around. If you've got a small screwdriver or anything (nail) it's easy to switch the contacts as in that photo.

Closed 2022-01-24.

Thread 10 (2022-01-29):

Device works but HV LED won't turn on

mehdideveloper, 2022-01-29:
Hi
So I built a second unit and everything seems fine. I measured the voltages, following Colin's Youtube video:
The test header (J3) shows around 228V. When I press the PULSE button, the voltage goes down and again recovers to ~228V.
Also the CHG header measures 2V when the ARMING LED is ON, and 0.77V when it's ON.
And I also tested the device on some STM32 dev boards and a Nintendo Game&Watch, and using the PicoEMP on the STM32, resets the device (actually bricked the Nintendo!)
So apparently it's working as expected.

However, the HV LED never turns on. I press the ARM and ARMING LED turns on, and that's it. It turns off after a minute or so.
Do you have any hints on how I can troubleshoot it?

colinoflynn, 2022-01-29:
Is the voltage on the HV led output OK (should go from 0V to 3.3V roughly for example)? Could be just a regular bad solder etc there if you see the voltage. The easiest way is just change the firmware to turn the HV led on and confirm that works?

A 'todo' was measuring the actual CHARGE pin voltage - basically the current FW uses the digital status of that pin, but you can measure the analog voltage as well to get a better indicator. So it also could be the input voltage isn't being read correctly, the 2V level is around the threshold of high/low IIRC (but that is roughly what it *should* read - so I don't think you've got an error).

Once the firmware supports reading the voltage can just use the analog value instead.

invd, 2022-01-30:
@mehdideveloper : wild guess, is it possible that you've soldered in the HV LED in the reverse orientation?
I've noticed during assembly that the two Kingbright LED color variants have their die on different sides of the package, so that's an easy error if installed "the same way".

mehdideveloper, 2022-01-30:
@invd Well, I double checked. Orientation is correct. I compared it with the other RED LED on the board. Actually in my case, the green and red LEDs are pointed visually the same way.
I measured the voltage across its pins, and there's no voltage, which means (as Colin said) probably the high/low is not being read/set correctly. It's not a big deal though, as the device works as expected.

hexsecs, 2022-06-14:
I'm also having the no HV LED issue. I think the LED itself may be bad.

I wrote a quick test to turn on all of the LEDs on the board. I'm seeing 3.3 V on both GP7 and GP8. 1.9V drop across the status LED (it's on). 3.3 V drop across HV LED. It is off. With board unplugged I tested all of the board LEDs with my multimeter diode tester. Status, Pico LED, and Arm all lit up successfully. No go on HV.

```python
from machine import Pin, Signal

# Status LEDs:
ledHv = Signal(Pin(6, Pin.OUT)) #HV 'on' LED (based on feedback)
ledHv.on()

ledArm = Signal(Pin(27, Pin.OUT)) #Arm 'on' LED
ledArm.on()

ledStatus = Signal(Pin(7, Pin.OUT)) #Simple status LED
ledStatus.on()

ledPi = Signal(Pin(25, Pin.OUT))
ledPi.on()
```

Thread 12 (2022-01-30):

Documentation suggestions

invd, 2022-01-30:
* Currently the `README.md` does not explain what `J3` and `SW3` are for. This is only mentioned in the introduction video.
* `Q1`, `D8` and `D9` have no easily visible orientation mark on the silkscreen, but the build-drawing PDF helps a bit.
* It is not clear if the device is allowed to have voltage on `J2` at the same time the USB port is used and how it will behave. Based on a _short_ look at the Pico2040 [datasheet](https://datasheets.raspberrypi.com/pico/pico-datasheet.pdf) on page 19, dual operation is acceptable and the USB power supply will become the primary due to its higher supply voltage after the Schottky diode compared to the 2xAA source + Schottky. However, the datasheet notes that USB _is required_ if the pico firmware uses USB host mode, which may be the case with the C firmware version.

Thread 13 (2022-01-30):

Options for increased maximum output power?

invd, 2022-01-30:
_Preface: I'm not an expert at high voltage electronics. Do not rely on any of the assumptions in this post. Do any modifications at your own risk._

Based on my understanding of the picoemp design, capacitor `C3` stores about `(0,47µF * (250V)^2)/2 = 14,69mJ` of energy assuming a charge voltage of 250V, a part of which can be used for a discharge into the coil. In the [introduction video](https://www.youtube.com/watch?v=nB5arJi-tVE&t=180s), the measured charge voltage is about 239V and I've measured about 258V on my own unit, so 250V looks reasonable as a ballpark figure.

"Bigger" designs like the regular chipShouter, siliconToaster etc. allow higher capacitor voltages in the area of 500V-1200V at their highest settings which significantly benefits the energy storage through the quadratic component. It would probably be possible to tweak the picoemp to work at a higher voltage than 250V (for example 300-400V), but I'm very cautious about such a modification since this reduces the safety margin for breakdown voltages (IGBT, capacitor, ..) and physical board or probe tip clearances. It would be very unfortunate if boards have a catastrophic breakdown due to left-over solder paste, partially exposed traces, ringing with mismatched experimental probe tips or one of the many other failure modes for self-assembled boards.

So I have been wondering about the benefits or drawbacks of increasing just the size the capacitor "bank" at `C3` by factor two to four. The standard picoemp design is clearly limited by the BOM cost and area/height under the plastic shield, so it is logical to me that "only" a single capacitor was chosen. (Also note that the Hammond 1551 enclosure has an additional plastic part in that corner of the board which needs to be stripped before that space is usable for high components).

@colinoflynn
Are you aware of any direct electrical drawbacks to doubling `C3` by stacking an identical 2.5mm height capacitor on top (which could _just_ fit the enclosure) for people who have used the thinner TDK `CGA9P1X7T2J474K250KE` per your BOM recommendations since Murata `KRM55TR72J474MH01K` wasn't available?
Alternatively, there appear to be a few capacitor candidates with nominal 1µF which are thin enough to fit under the shield (untested candidates: Kyocera AVX `2220CC105KAZ2A`, Knowles Syfer `2220Y6300105KXTWS2` and its more expensive AEC-Q200 twin). Based on the datasheets, 1 to 1.2µF is the upper end of capacitors in this package size at 630V, so there may be capacitor design limitation drawbacks that I'm not aware of which motivate staying at the slightly more conservative 0.47µF choice.
With a custom 3D-printed shield and larger inner shield height, it looks possible to stack some more capacitors on C3 and go for the mentioned 4x capacitor increase.

Looking at the PCB layout, it _may_ be possible to rotate the `C3` component counter-clockwise and squeeze another `2220` footprint into the layout for optional used by people who want the additional BOM cost for higher capacity trade-off. It's probably going to be fairly close to the plastic shield mounting clearance, though. (_Related idea: it looks like R2 and J3 could be swapped and J3 turned counter-clockwise to simplify the trace routing and increase distances. However, this takes more space along the shield and therefore works against adding another capacitor footprint_).

From what I can tell, the recharge rate of the capacitor bank will not change with a size increase, so I expect the main effect to be a larger initial energy supply.

colinoflynn, 2022-01-30:
A larger cap will slow down the recharge (the current design is already fairly low). However be aware that the limiting factor is almost always the coil you inject this into, and NOT the capacitive bank.

The ChipSHOUTER manual has a figure showing the maximum pulse width you see at the output showing this:
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

The problem is the core material saturates at some point (or I think that is the problem). Larger tips allow wider pulse widths. The main advantage of a larger bank is faster repeats (no recharge time needed), but this significantly complicates drive + cooling problems.

Generally though bigger is not always better (often it is worse), especially where there is no voltage control (as in PicoEMP). It makes the rest of your design more difficult & reduces reliability while increasing cost (you need a larger MOSFET which adds cost, then you need a much more complex gate drive since that MOSFET has a larger gate capacitance, etc etc).

Of course people are free to fork the design to try it out, one of the ideas of this! But I made the decision for PicoEMP to simplify it as much as possible (but not more) to reduce cost while still allow recreation of many results.

Closed 2022-01-30.

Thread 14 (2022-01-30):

Unreliable arming button in C firmware

invd, 2022-01-30:
First of all, @nezza thank you for the C firmware!

On my unit, it's hit-or-miss whether pressing the "arming" button actually toggles the arming state as intended. In my impression, short clicks are slightly more reliable, but I don't see a clear pattern.
Typically, the arming-LED goes on or off briefly during the button click, but doesn't stay at the intended toggled state. This _may_ be related to the [button debouncing logic](https://github.com/newaetech/chipshouter-picoemp/blob/13469fb257479e7d68553232548c6708e06f7ab3/firmware/c/main.c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) but I haven't looked at the code in any depth so far.

Changing the state via USB-serial is reliable and without any issues. I have not tried the micropython firmware version.

nezza, 2022-01-30:
Hey!

The debouncing is definitely a bit too enterprise-grade at the moment 🙃
I haven't encountered this issue yet, but will check in the next days

Cheers,
Thomas

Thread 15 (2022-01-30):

Relevance of additional TVS output filtering diode

invd, 2022-01-30:
There is a paper by Toulemont, J., et al. on _"A Simple Protocol to Compare EMFI Platforms."_ which suggests that the ringing/reflection at the coil immediately after a high voltage pulse is a problem and that it can be limited through the use of an inexpensive diode (2020, [IACR preprint](https://eprint.iacr.org/2020/1277.pdf)).

They propose adding an unidirectional Littlefuse `1.5KE600A` transient voltage suppressor (TVS) diode between the voltage generation output and the probe tip to clamp some of the voltage swings.

Based on the tests shown [in the introduction video](https://www.youtube.com/watch?v=nB5arJi-tVE&t=390s), there are not a lot of oscillation cycles for the tested coil on the picoemp, so the main benefit I can see is to reduce the second half-wave of the pulse and maybe reduce the first oscillation after that. However, I'm not sure in if this would result in noticeable benefits during picoemp usage since timing considerations are probably not as important for picoemp users and the second full cycle may not actually inject much voltage into the target.
So the improvement could be to suppress the reverse injection effects of the second half-wave on the target and make the picoemp slightly more targeted/precise? I'm not certain I've gotten the physics right here, so this is very speculative.

The ca. 250V maximum capacitor voltage of the picoemp looks compatible with the min. 570V breakdown voltage safety rating of the mentioned diode, the diode is currently available & low cost, which are some of the reasons I'm considering this. The diode could be located on a small SMA-based filter (as used in the paper) or built directly into custom probe tips (incompatible with higher-voltage glitchers).

@colinoflynn
You're likely aware of this protection diode concept, what are your thoughts on this? Is it relevant within the typical picoemp pulse behavior and parameters?
Thanks!

colinoflynn, 2022-01-30:
Worth a try! FYI the IGBT itself has a "built-in" diode which is why there is no stand-alone one ("built in" but really part of the design of the IGB), so I think where there isn't much cabling between the SMA and coil you won't see that much difference. It would likely make a larger difference if you had a cable between the SMA output and coil. Interestingly with the larger ChipSHOUTER some people use it that way (a SMA cable between the output & the injection tip).

The Toulemont et al paper is using a pulse generator, so it's unclear if it would have this built into the output (depends on the output architecture). Either way if you had cabling from the output to the coil (as they would), I'd expect the diode being present close to the coil to matter more for their use-case.

FYI a better place to discuss (feel free to copy/paste this there) is the https://forum.newae.com area which tracks discussions like this across multiple projects, including ChipSHOUTER users.

Closed 2022-01-30.

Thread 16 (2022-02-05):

It's possible to shock computer even through USB isolator on target, beware!

hiviah, 2022-02-05:
I was using this isolator - https://www.aliexpress.com/item/4000047053305.html (mentioned in https://github.com/newaetech/chipshouter-picoemp/issues/2#issuecomment-999962799) as intermediate between computer and target (Atmega328), PicoEMP on completely separate power source (since I needed to see USB-serial output to see if glitch was success).

Somehow during the session I managed to shock USB bus through Atmega target connected via the isolator on both computer and monitor USB hubs so they disconnected (power cycling did fix it, so nothing permanent thank god). I am pretty sure I did not short anything, but even in that case the isolator is rated according to docs to 1.5 kV. So this shoudln't have happened, but the quality of the isolator is also question.

There was a powered hub behind the the USB isolator (Atmega<->USB isolator<->powered USB hub<->computer+monitor), but I seriously have no idea which part of the setup could have caused this. Hundreds of glitch attempts were fine until this one.

Even if this was some stupid mistake, there was definitely no direct contact between any parts after the USB isolator.

colinoflynn, 2022-02-05:
The isolators are rated for DC, so indeed these AC pulses may pass through somewhat due to capacitive coupling. The energy in the AC pules should be low enough that (hopefully) the ESD diodes and similar will catch it. The USB interfaces should have good protection there due to how much ESD they are subject to normally (people grabbing the far end of a 1m long USB cable).

But also the USB ports *will* get shut down if they see too many errors at the protocol layer (ask anyone doing USB development at least on Windows... eventually you need to reboot your computer as the ports get turned off). So it's possible for this to happen even if there were no issues with the isolator too, just from glitchy USB traffic.

If you're working with a serial target & want total safety, you might consider using an optoisolator on those serial lines, i.e.:

```
    +----   +5V Isolated -----------+           
    |                               |
+-----------------+    rx/tx/nRST   |
|    ATMEGA       |     <--- OPTO/ISOLATOR ---> USB-SERIAL CHIP <-----> COMPUTER
+-----------------+
```

hiviah, 2022-02-05:
Thanks!

I've shorted USB bus twice in life by mistake (connecting VBUS +5V to GND accidentally on devboard due to rat's nest wiring), but usually what computer did was disconnect that specific physical connector (bus) and just reconnect fixed it.

In this case all USB physical ports computer+monitor became disconnected until power cycle on all devices which I haven't seen before.

Going to go for opto isolators from now on. Though on datasheet the [ADuM3160](https://www.analog.com/media/en/technical-documentation/data-sheets/adum3160.pdf) on page 6 it says it should handle 560V AC.

On a separate note, would there be a way to repurpose these HDMI optical cables for ETM TRACE as opto isolators? https://twitter.com/jaydcarlson/status/1483162491022712832

colinoflynn, 2022-02-06:
ETM trace is probably going to be tricky, as it seems sensitive to timing even when working normally... tbh I wouldn't worry about isolating the target. I never bother with that and haven't killed anything (you may have a different experience). I *do* add series resistors + ESD/diode clamps though, but basically the actual "injected" voltage isn't likely to be very high (unless you directly short the coil to the target!).

mrx23dot, 2024-02-27:
would be better to use simple UART with opto isolation or RF instead of usb.

Closed 2022-02-06.

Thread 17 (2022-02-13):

BOM description mistake

K7cl, 2022-02-13:
Q3, Q4 in BOM excel description is _MOSFET   N-CH 30V 2.2A SOT23-3_, but part number AO3422 refer to it's datasheet is 55V 2.1A

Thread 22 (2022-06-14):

Voltage on a TIP

gmgunderground, 2022-06-14:
How do you like the signal measured on the tip?
Does it seem to work correctly?
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

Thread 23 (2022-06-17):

Performance

gmgunderground, 2022-06-17:
Ho number of turns, presence or not of ferrite and shape influence the strength of magnetic field?

GOHSTMODEM, 2023-10-29:
Bonjour peut on sonder un appareil électroniques avec un pico shooter avec une tension basse? Merci

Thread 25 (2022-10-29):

Problem with Build : HV Led wont turn on / Only 7V Voltage

dwelltime, 2022-10-29:
Hello

I have some issues with building this nice device.all parts were used from the bom list except RGT16BM65DT i used instead IKD06N60RATMA1.Gerber files used were rev04_normal.zip also with milled slots for the protection shield.

The solder orientation for the LEDs wasnt so clear to me,so i modified the micropython firmware to run a LED check on startup which works great.

So the actual problem :

The test header (J3) shows only 7V when the ARM button is pressed but the HV LED wont turn on so Pulse doesnt work either.Voltage on (P3) is approx 3V which seems to be correct.Discharge button works.

I looked at the firmware and changed the PWM duty which seems also to work i gained then 12V but its still alot missing hehe

Somewhere i did an error i think but i also rechecked already the solder orientation for the different smd parts.
So can anyone please point me in the right direction and give me some hint?
Should i maybe test the C Firmware? But there is also still some issue with the arming button ive read.

Thanks

Greetings

tymmothy, 2024-06-27:
Hi - is there any chance that you used a Pi Pico clone? I just debugged a similar situation and tracked it down to the SMPS on the clone not working properly. The board depends on the Pico's SMPS outputting 3.3V; on mine it was putting out the same voltage as the input (which came to about 2.3V after the input protection diode). In my case, it would work as expected when powered from USB, but using a 3V battery pack would lead to the same 7V on the HV rail.

I swapped out the Pico clone for a genuine board and am now seeing arming work as intended and 246V on the HV rail on 3V battery power.

dwelltime, 2024-07-10:
hello!

no i took the official gerber files and made some boards with jlcpcb.then i ordered an picoemp from newatech directly which works.
i still would like to fix the issue :/

tymmothy, 2024-07-10:
Do you mind measuring the voltage on the "3v3(OUT)" pin (P36)? in my case as mentioned I was only seeing about 2.3V (which was too low to properly power the high voltage converter).

Also - have you tried running from USB power?

dwelltime, 2024-07-10:
i think i have the same issue i dont remember correctly i will measure later and report.yes ive also tried to power from usb of course

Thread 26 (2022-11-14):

Flyback old TV.

autoprog, 2022-11-14:
hi,
I would like to know if it would work with old TV Flyback.
Yoke part has 1000v for 15750hz.
could use a FET IGBT switch to turn it on for x time.

thanks,
Carlos.

Closed 2023-02-05.

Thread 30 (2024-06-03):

Request HVPWM explanation

gmgunderground, 2024-06-03:
I'm looking inside the C source code, can someone explane the following function? Especially the used values.

```
void picoemp_enable_pwm(float duty_frac) {
    if(pwm_enabled) {
        return;
    }

    // Get PWM slice
    uint32_t slice = pwm_gpio_to_slice_num(PIN_OUT_HVPWM);
    gpio_set_function(PIN_OUT_HVPWM, GPIO_FUNC_PWM);

    // Set up clock divider
    float target_frequency = 25;
    float divider = clock_get_hz(clk_sys) / target_frequency;
    pwm_config config = pwm_get_default_config();
    pwm_config_set_clkdiv(&config, divider);
    pwm_config_set_wrap(&config, UINT16_MAX);

    // Init PWM, but don't start it yet
    pwm_init(slice, &config, false);
    // pwm_set_chan_level(slice, PWM_CHAN_A, 800); // pretty sure this line is pointless
    pwm_set_freq_duty(slice, PWM_CHAN_A, 2500, duty_frac);
    pwm_set_enabled(slice, true);
    pwm_enabled = true;
}

```

what the The duty_frac  is used for? How is correlated to the power?
What are the bahavior of the following parameters?
pulse_time=5, pulse_power=0.012200
Are parameters that it's worth a change?

colinoflynn, 2024-06-04:
It might make more sense looking at the micropython source: https://github.com/newaetech/chipshouter-picoemp/blob/main/firmware/micropython/cspico_simple.py#L16

That has the short note that things were basically just empirically tuned! So there's no real magic... you could play around with things and see what happens to the charge voltage and/or recovery time?

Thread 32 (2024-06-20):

PicoEMP pinout doubts

ic32k, 2024-06-20:
Hello,

I was looking for some more info abut the pinout of the PicoEMP. and what could be his possible usage....

I saw the introduction video, thus also tried to find other videos to see how they use it but there is no may out there, also tried to look for info in the ‘user manual’ of ChipShouter, but I was’t lucky enough to find the usage of the pins, so here are my questions

It has 3 pin headers:
P1: GP0 to GP5 and GND
P2: HVP and GND
P3: CHG, VCC, GND and PWM

The readme says “External HVP mode: a pulse generator can be used to control EM pulse insertion”, so I understand it must be connected to P2 header and I can attach to it any 'clock source', but how we control when the pulse is done with this mode?

Also says “Fast triggering using GPIO0” this is GP0 from pin header P1, isn’t it? It can be used to connect GPIO4 from target board and trigger a pulse when rising edge is received like with chipwhisperer? or maybe that fast triggering is taking GP0 to VCC/GND?

What are header P3’s “CHG” and “PWM” pins for?

Also wanted to know if the pulse power value of the source code (#define PULSE_POWER_DEFAULT 0.0122) has direct relation with the coil tip characteristics, and if so how can we make calculations to keep it under safe values? IDK maybe there is a min or max level can be configured based on uH value of the coil like let’s say I have a coil with 0.8mm wire, 4mm diameter 15 windings and 3.3uH so calculating X Z and Y the safe or valid power values are from 0.0050 to 1.3259 (This values are completely fictitious)

And the last question... What this GP1 used for? GP2 to GP5 has any use?

Thank for your help guys!!!

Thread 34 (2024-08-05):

Discharge button access

gashtaan, 2024-08-05:
I initially thought that when I use exact parts TL3301AF160QJ switch and 1551BTRD shield, it would be somehow possible to press the discharge switch pushing it by pressing the shield above it. The shield fits perfectly to my PCB, but it doesn't work that way - button is too low and/or shield too sturdy. How was it intended?

The button height is 5mm, inner depth of the shield is 5.5mm.

colinoflynn, 2024-08-06:
This is intended - when you remove the shield, you need to manually push the discharge button yourself. Basically it's a nicer way of discharging, even if not fully foolproof. You can drill a small hole in the shield & then use a small dowel or similar to discharge it is basically the best "fully safe" way.

The ceramic caps don't hold their charge too long compared to e.g., a Xenon flash capacitor, so ultimately most of the time it does drain off unless you are removing the shield shortly after having it on (which hopefully means you remember to discharge it first!).

Using a NC button that has a longer pluged so it automatically discharges was a possability, but it became an issue that (1) NC isn't readibly available in pushbuttons, and (2) it can be helpful for debug running with the shield off (or doing voltage vs. PWM curves).

gashtaan, 2024-08-06:
So I've overthinked it a bit :) I just thought that button will be possible to press through the shield (be deforming it a little).

Closed 2024-08-06.

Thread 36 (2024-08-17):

US1J-13-F as D2

gashtaan, 2024-08-17:
You mentioned diode US1J-13-F as known D2 substitution, but you've never tested it. I'm using it in my build and output seems correct I guess. This is what I measured on the coil:

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

colinoflynn, 2024-08-18:
Thanks for confirming! We had used some in a test build as well, although hadn't finished checking it yet ourselves. We may be swapping to that in our builds so will update the BOM to include this note!

Closed 2024-08-18.

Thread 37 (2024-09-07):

Ticking sound

gashtaan, 2024-09-07:
Anyone experiencing quite loud ticking sound coming from somewhere around C3 capacitor, Q2 transistor when firing the pulse? It's difficult to pin-point the exact location, I rather not to keep my ear too close to this high voltage circuit :)

I suspect some piezo-electric effect in capacitor. I chosen GRM55DR7LV474KW01K for this part.

colinoflynn, 2024-09-09:
You are correct - the capacitor will do that! It happens with the discharge due to the fast discharge current / voltage change. In fact the larger ChipSHOUTER capacitors have little metal "tabs" to help absorb some of the movement as you can otherwise cause solder joint damage from the movement of the caps over many discharge cycles (the ChipSHOUTER caps are larger & have a higher current change).

gashtaan, 2024-09-09:
@colinoflynn Will use of capacitor with flexible termination less noisy? Or there is nothing to do about it?

colinoflynn, 2024-09-10:
I'm not sure if less noisy - the noise isn't something I guess I was worried about before, normally I think it's a good thing as you know it's working!

gashtaan, 2024-09-10:
> normally I think it's a good thing as you know it's working!

That's true, initially I thought the same. Although at first I thought it's caused by movement of loose wires in the coil which I can easily solve. The problem is that I want to use it in some automation over extended period of the time, but because of that ticking I can't keep it running overnight or during baby's naps :)

Anyway, at least I know the noise is normal and expected. Thanks for the info.

colinoflynn, 2024-09-10:
Some movement of the loose wires in the coil also causes sound, this is more obvious in the larger ChipSHOUTER. If noise is a problem I'd try dabbing a bunch of silicon sealant around the capacitor (ideally something that is designed for electronics, *not* stuff that smells like vinegar as that smell is acetic acid & will cause rapid corrosion). You could try some hot glue or something else too. Even a small piece of foam maybe... the cap won't have too much heat, you may want to leave a little room for the coil to have heat dissipation, but even that shouldn't be too terrible.

gashtaan, 2024-09-27:
@colinoflynn I just swapped the C3 capacitor to KRM55TR72J474MH01K (the one you've recommended in BOM parts). It still makes the ticking sound, but now it's hardly noticeable. The difference is enormous. I shouldn't have experimented with it :)

Closed 2024-09-10.

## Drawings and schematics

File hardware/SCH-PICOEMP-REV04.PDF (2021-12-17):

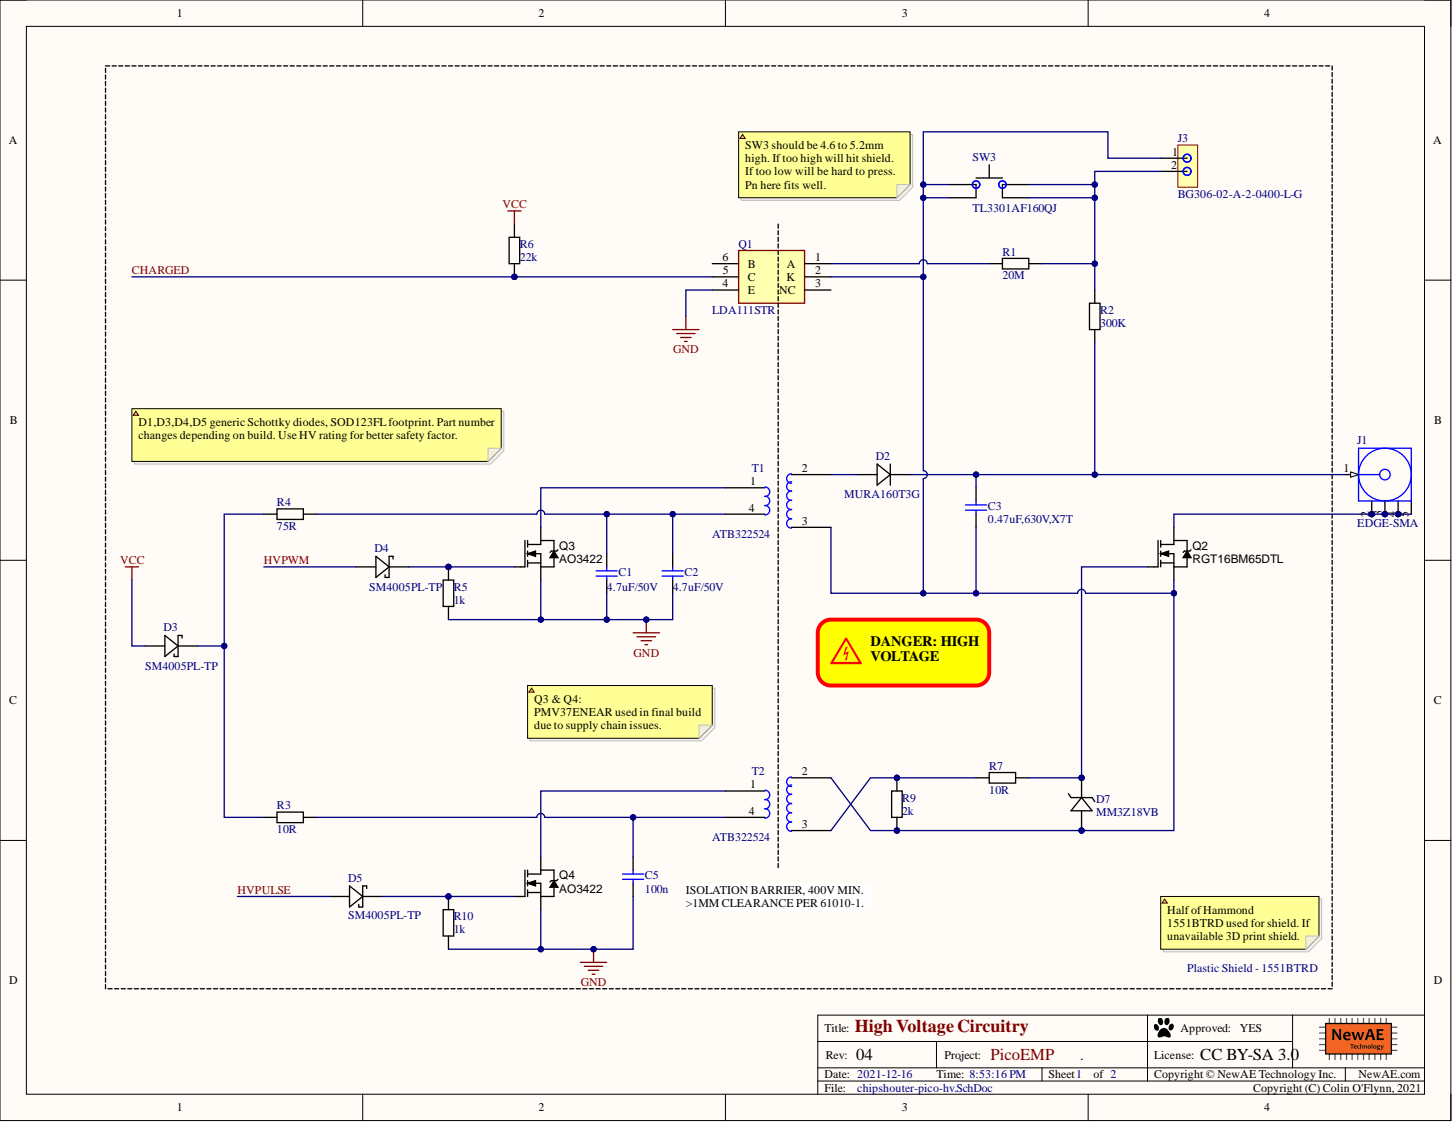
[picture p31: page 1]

SW3 should be 4.6 to 5.2mm
high. If too high will hit shield.
If too low will be hard to press.
Pn here fits well.

D1,D3,D4,D5 generic Schottky diodes, SOD123FL footprint. Part number
changes depending on build. Use HV rating for better safety factor.

PMV37ENEAR used in final build
due to supply chain issues.

Half of Hammond
1551BTRD used for shield. If
unavailable 3D print shield.

High Voltage Circuitry
Title:
Rev:
chipshouter-pico-hv.SchDoc

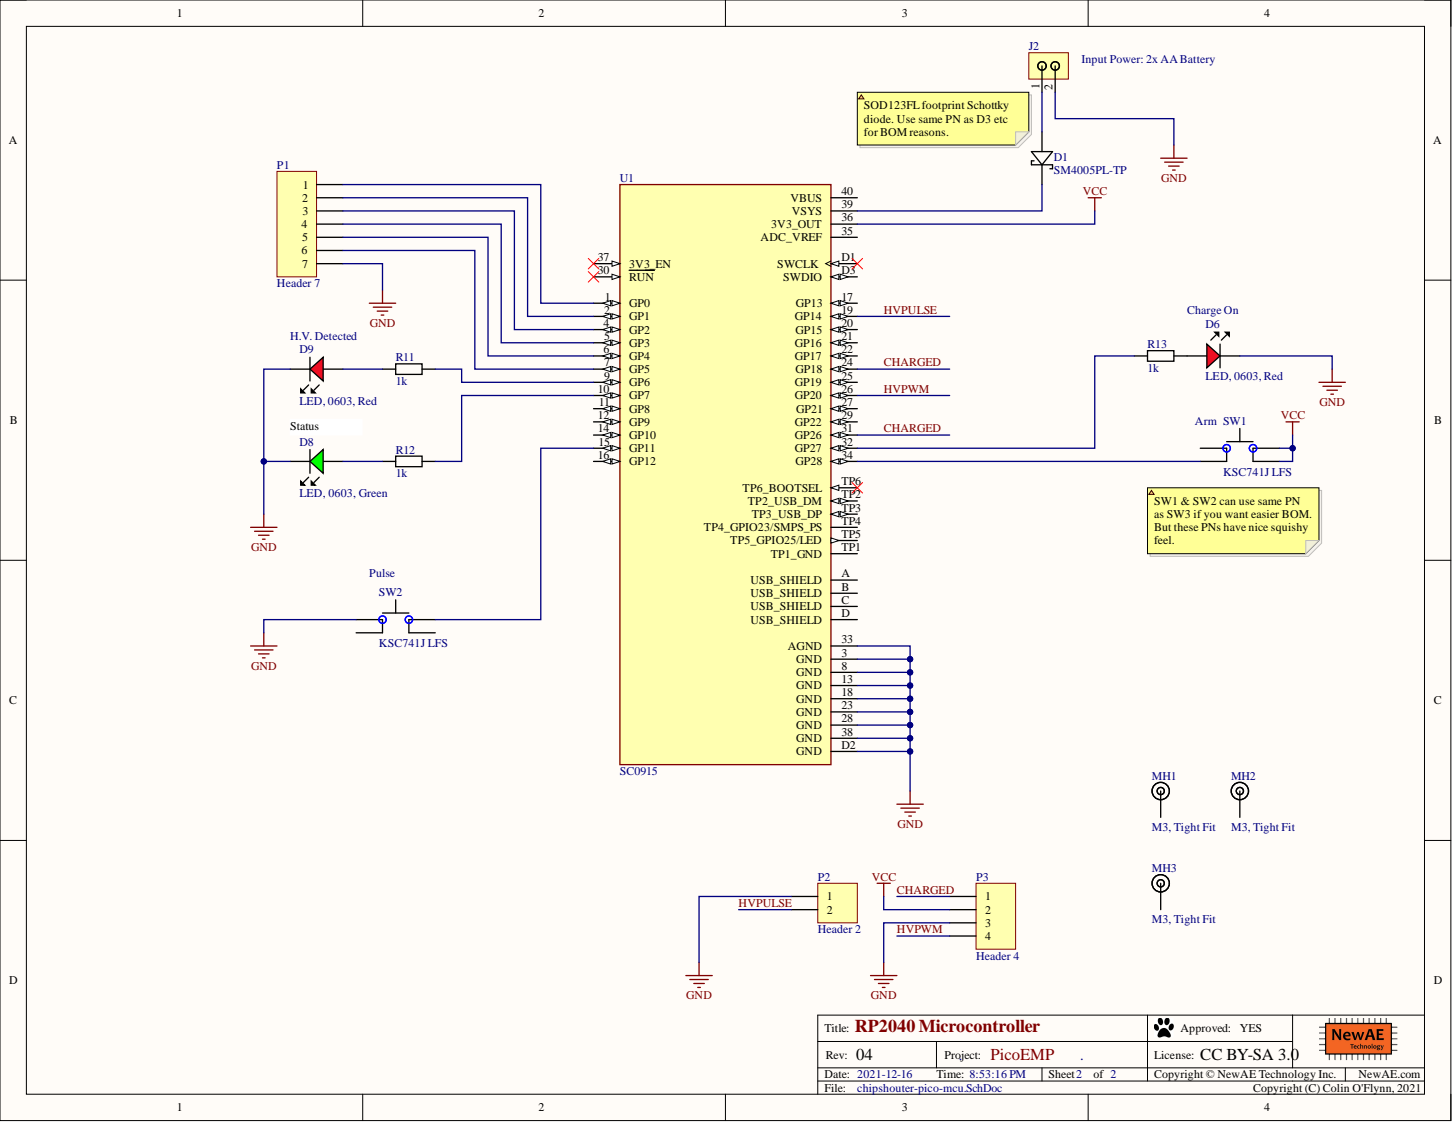
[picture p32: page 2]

Input Power: 2x AA Battery

SOD123FL footprint Schottky
diode. Use same PN as D3 etc
for BOM reasons.

GND | GP2 4

GP3 5
GP4 6

R11 | GP5 7 GP6 9 | CHARGED

SW1 & SW2 can use same PN
as SW3 if you want easier BOM.
But these PNs have nice squishy
feel.

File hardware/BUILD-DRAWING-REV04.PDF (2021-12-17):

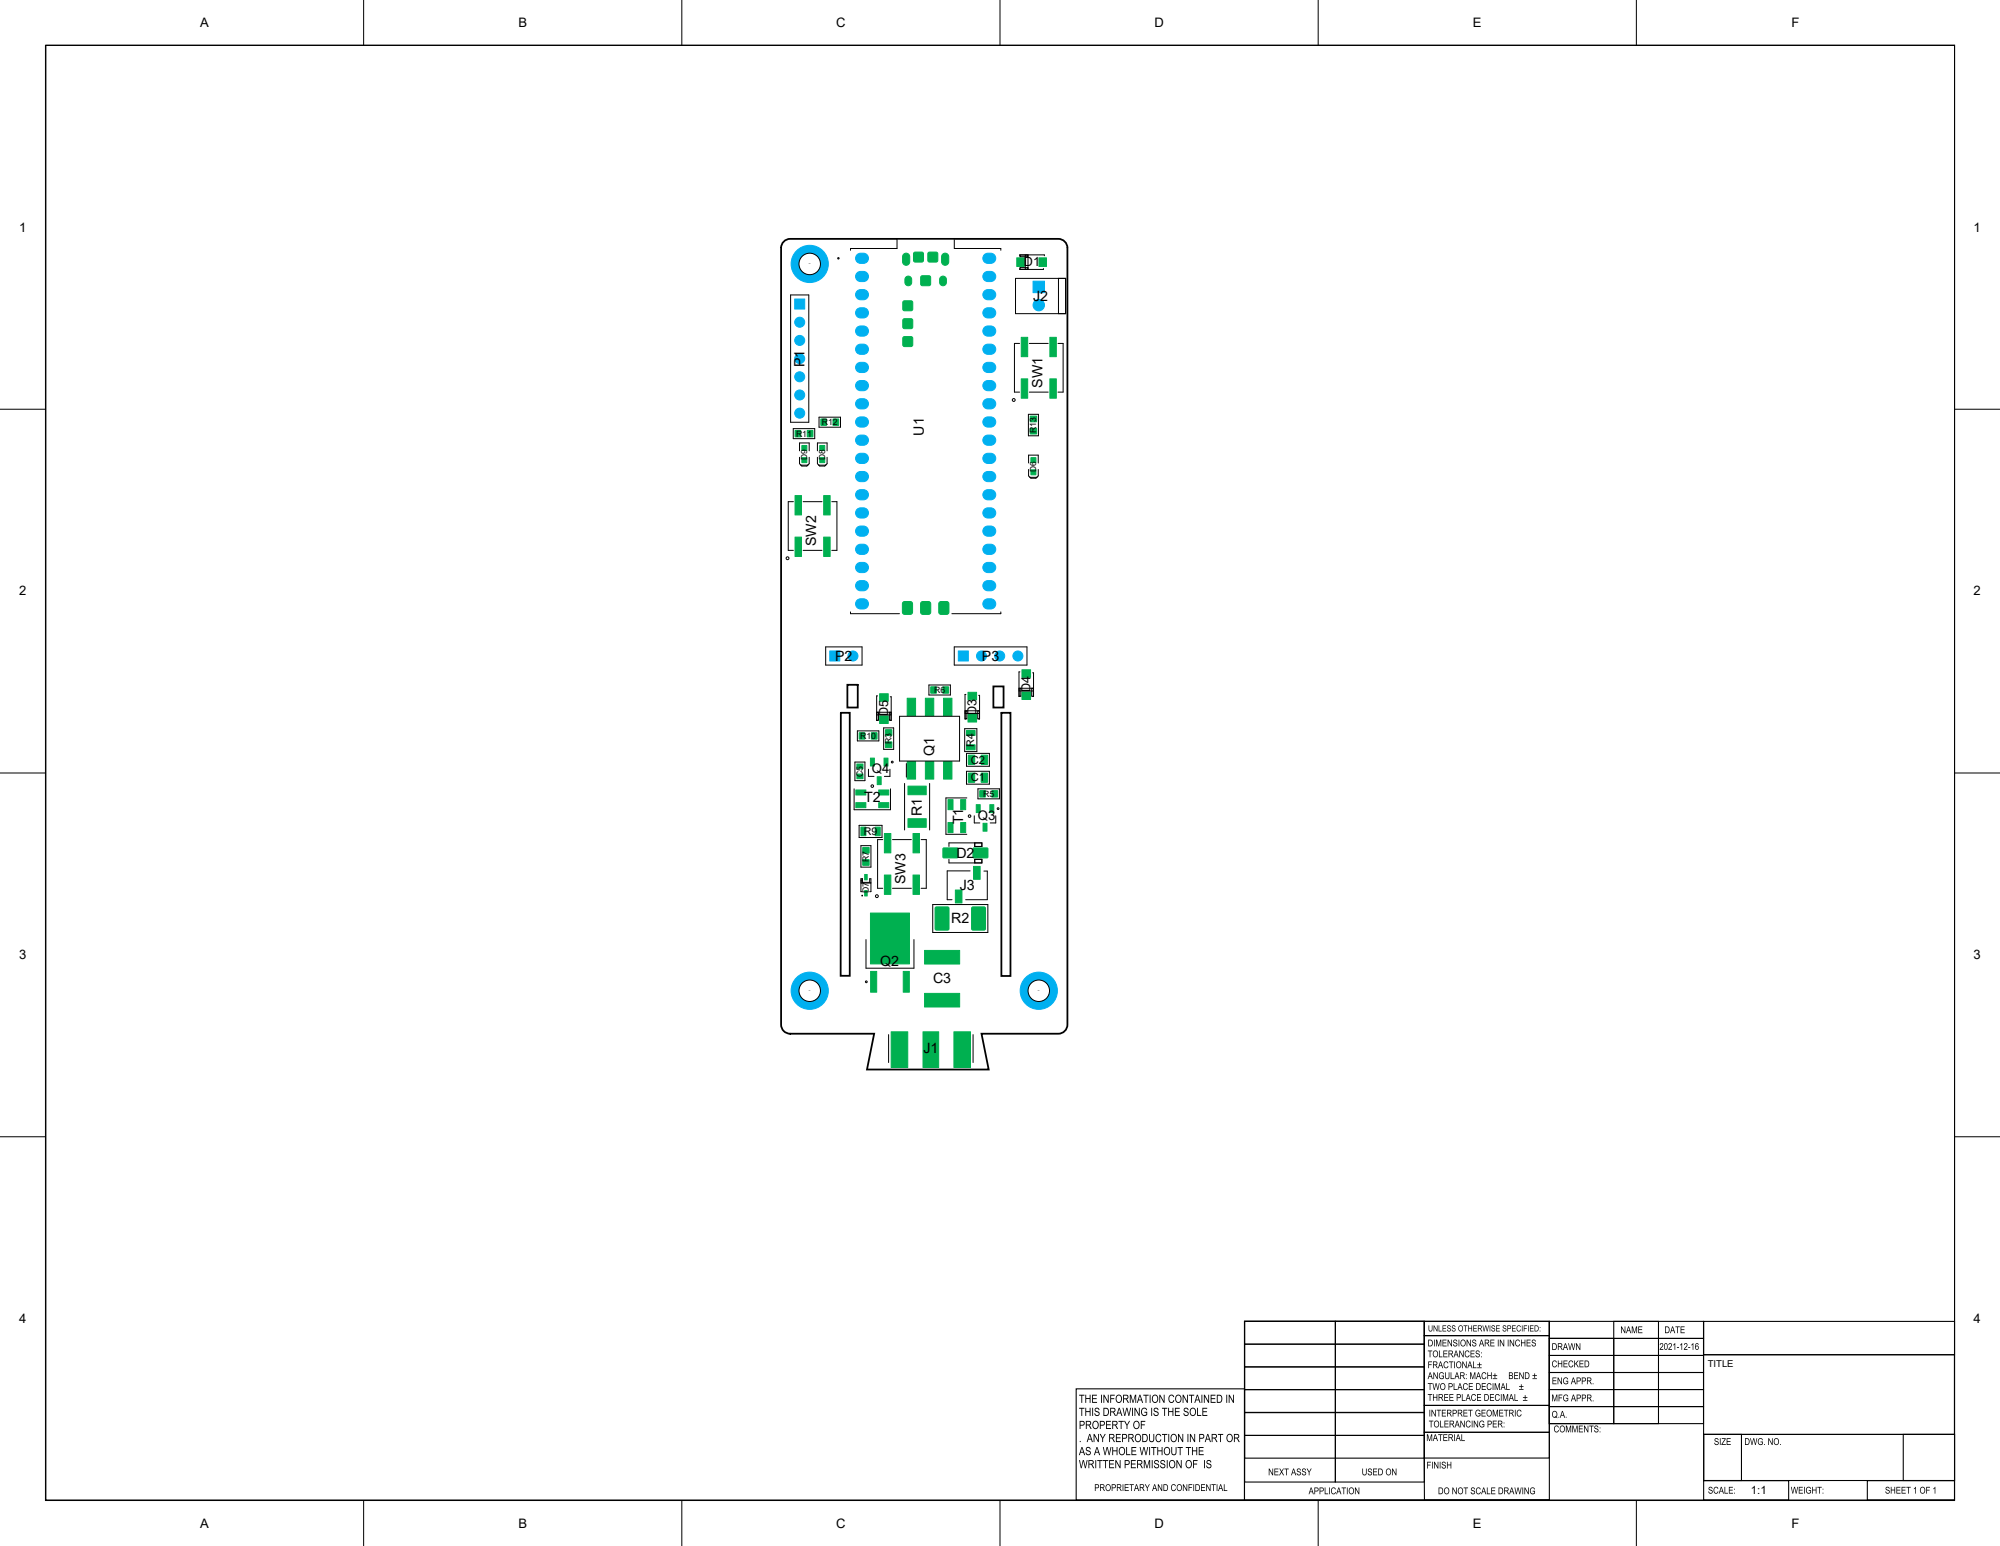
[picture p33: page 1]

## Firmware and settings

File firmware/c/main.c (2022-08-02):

#include <stdio.h>
#include <string.h>

#include "pico/stdlib.h"
#include "pico/multicore.h"

#include "picoemp.h"
#include "serial.h"

#include "trigger_basic.pio.h"

static bool armed = false;
static bool timeout_active = true;
static bool hvp_internal = true;
static absolute_time_t timeout_time;
static uint offset = 0xFFFFFFFF;

// defaults taken from original code
#define PULSE_DELAY_CYCLES_DEFAULT 0
#define PULSE_TIME_CYCLES_DEFAULT 625 // 5us in 8ns cycles
#define PULSE_TIME_US_DEFAULT 5 // 5us
#define PULSE_POWER_DEFAULT 0.0122
static uint32_t pulse_time;
static uint32_t pulse_delay_cycles;
static uint32_t pulse_time_cycles;
static union float_union {float f; uint32_t ui32;} pulse_power;

void arm() {
    gpio_put(PIN_LED_CHARGE_ON, true);
    armed = true;
}

void disarm() {
    gpio_put(PIN_LED_CHARGE_ON, false);
    armed = false;
    picoemp_disable_pwm();
}

uint32_t get_status() {
    uint32_t result = 0;
    if(armed) {
        result |= 0b1;
    }
    if(gpio_get(PIN_IN_CHARGED)) {
        result |= 0b10;
    }
    if(timeout_active) {
        result |= 0b100;
    }
    if(hvp_internal) {
        result |= 0b1000;
    }
    return result;
}

void update_timeout() {
    timeout_time = delayed_by_ms(get_absolute_time(), 60 * 1000);
}

void fast_trigger() {
    // Choose which PIO instance to use (there are two instances)
    PIO pio = pio0;

    // Our assembled program needs to be loaded into this PIO's instruction
    // memory. This SDK function will find a location (offset) in the
    // instruction memory where there is enough space for our program. We need
    // to remember this location!
    if (offset == 0xFFFFFFFF) { // Only load the program once
        offset = pio_add_program(pio, &trigger_basic_program);
    }
    
    // Find a free state machine on our chosen PIO (erroring if there are
    // none). Configure it to run our program, and start it, using the
    // helper function we included in our .pio file.
    uint sm = 0;
    trigger_basic_init(pio, sm, offset, PIN_IN_TRIGGER, PIN_OUT_HVPULSE);
    pio_sm_put_blocking(pio, sm, pulse_delay_cycles);
    pio_sm_put_blocking(pio, sm, pulse_time_cycles);

}

int main() {
    // Initialize USB-UART as STDIO
    stdio_init_all();

    picoemp_init();

    // Init for reset pin (move somewhere else)
    gpio_init(1);
    gpio_set_dir(1, GPIO_OUT);
    gpio_put(1, 1);

    // Run serial-console on second core
    multicore_launch_core1(serial_console);

    pulse_time = PULSE_TIME_US_DEFAULT;
    pulse_power.f = PULSE_POWER_DEFAULT;
    pulse_delay_cycles = PULSE_DELAY_CYCLES_DEFAULT;
    pulse_time_cycles = PULSE_TIME_CYCLES_DEFAULT;

    while(1) {
        gpio_put(PIN_LED_HV, gpio_get(PIN_IN_CHARGED));

        // Handle serial commands (if any)
        while(multicore_fifo_rvalid()) {
            uint32_t command = multicore_fifo_pop_blocking();
            switch(command) {
                case cmd_arm:
                    arm();
                    update_timeout();
                    multicore_fifo_push_blocking(return_ok);
                    break;
                case cmd_disarm:
                    disarm();
                    multicore_fifo_push_blocking(return_ok);
                    break;
                case cmd_pulse:
                    picoemp_pulse(pulse_time);
                    update_timeout();
                    multicore_fifo_push_blocking(return_ok);
                    break;
                case cmd_status:
                    multicore_fifo_push_blocking(return_ok);
                    multicore_fifo_push_blocking(get_status());
                    break;
                case cmd_enable_timeout:
                    timeout_active = true;
                    update_timeout();
                    multicore_fifo_push_blocking(return_ok);
                    break;
                case cmd_disable_timeout:
                    timeout_active = false;
                    multicore_fifo_push_blocking(return_ok);
                    break;
                case cmd_config_pulse_delay_cycles:
                    pulse_delay_cycles = multicore_fifo_pop_blocking();
                    multicore_fifo_push_blocking(return_ok);
                    break;
                case cmd_config_pulse_time_cycles:
                    pulse_time_cycles = multicore_fifo_pop_blocking();
                    multicore_fifo_push_blocking(return_ok);
                    break;
                case cmd_fast_trigger:
                    fast_trigger();
                    multicore_fifo_push_blocking(return_ok);
                    while(!pio_interrupt_get(pio0, 0));
                    multicore_fifo_push_blocking(return_ok);
                    pio_sm_set_enabled(pio0, 0, false);
                    picoemp_configure_pulse_output();
                    break;
                case cmd_internal_hvp:
                    picoemp_configure_pulse_output();
                    hvp_internal = true;
                    multicore_fifo_push_blocking(return_ok);
                    break;
                case cmd_external_hvp:
                    picoemp_configure_pulse_external();
                    hvp_internal = false;
                    multicore_fifo_push_blocking(return_ok);
                    break;
                case cmd_config_pulse_time:
                    pulse_time = multicore_fifo_pop_blocking();
                    multicore_fifo_push_blocking(return_ok);
                    break;
                case cmd_config_pulse_power:
                    pulse_power.ui32 = multicore_fifo_pop_blocking();
                    multicore_fifo_push_blocking(return_ok);
                    break;
                case cmd_toggle_gp1:
                    gpio_xor_mask(1<<1);
                    multicore_fifo_push_blocking(return_ok);
                    break;
            }
        }

        // Pulse
        if(gpio_get(PIN_BTN_PULSE)) {
            update_timeout();
            picoemp_pulse(pulse_time);
        }

        if(gpio_get(PIN_BTN_ARM)) {
            update_timeout();
            if(!armed) {
                arm();
            } else {
                disarm();
            }
            // YOLO debouncing
            while(gpio_get(PIN_BTN_ARM));
            sleep_ms(100);
        }

        if(!gpio_get(PIN_IN_CHARGED) && armed) {
            picoemp_enable_pwm(pulse_power.f);
        }

        if(timeout_active && (get_absolute_time() > timeout_time) && armed) {
            disarm();
        }
    }
    
    return 0;
}

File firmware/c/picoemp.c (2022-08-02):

#include "picoemp.h"

#include "hardware/gpio.h"
#include "hardware/pwm.h"
#include "hardware/clocks.h"
#include "pico/stdlib.h"

#include <stdio.h>

const uint32_t PIN_IN_TRIGGER = 0; // also GP0 on the board
const uint32_t PIN_LED_HV = 6;
const uint32_t PIN_LED_STATUS = 7;
const uint32_t PIN_BTN_PULSE = 11;
const uint32_t PIN_OUT_HVPULSE = 14;
const uint32_t PIN_IN_CHARGED = 18;
const uint32_t PIN_OUT_HVPWM = 20;
const uint32_t PIN_LED_CHARGE_ON = 27;
const uint32_t PIN_BTN_ARM = 28;

static bool pwm_enabled = false;

// Code from https://www.i-programmer.info/programming/hardware/14849-the-pico-in-c-basic-pwm.html?start=2
uint32_t pwm_set_freq_duty(uint slice_num,
       uint chan, uint32_t f, float d)
{
    uint32_t clock = clock_get_hz(clk_sys);
    uint32_t divider16 = clock / f / 4096 + (clock % (f * 4096) != 0);
    
    if (divider16 / 16 == 0)
        divider16 = 16;
    
    uint32_t wrap = clock * 16 / divider16 / f - 1;
    
    pwm_set_clkdiv_int_frac(slice_num, divider16/16, divider16 & 0xF);
    pwm_set_wrap(slice_num, wrap);
    pwm_set_chan_level(slice_num, chan, (int)((float)wrap * d));
    
    return wrap;
}

void picoemp_enable_pwm(float duty_frac) {
    if(pwm_enabled) {
        return;
    }

    // Get PWM slice
    uint32_t slice = pwm_gpio_to_slice_num(PIN_OUT_HVPWM);
    gpio_set_function(PIN_OUT_HVPWM, GPIO_FUNC_PWM);
    
    // Set up clock divider
    float target_frequency = 25;
    float divider = clock_get_hz(clk_sys) / target_frequency;
    pwm_config config = pwm_get_default_config();
    pwm_config_set_clkdiv(&config, divider);
    pwm_config_set_wrap(&config, UINT16_MAX);

    // Init PWM, but don't start it yet
    pwm_init(slice, &config, false);
    // pwm_set_chan_level(slice, PWM_CHAN_A, 800); // pretty sure this line is pointless
    pwm_set_freq_duty(slice, PWM_CHAN_A, 2500, duty_frac);
    pwm_set_enabled(slice, true);
    pwm_enabled = true;
}

void picoemp_disable_pwm() {
    pwm_enabled = false;
    gpio_init(PIN_OUT_HVPWM);
    gpio_set_dir(PIN_OUT_HVPWM, GPIO_OUT);
    gpio_put(PIN_OUT_HVPWM, false);
}

void picoemp_pulse(uint32_t pulse_time) {
    gpio_put(PIN_OUT_HVPULSE, true);
    sleep_us(pulse_time);
    gpio_put(PIN_OUT_HVPULSE, false);
    sleep_ms(250);
}

void picoemp_configure_pulse_output() {
    // Configure pulse output
    gpio_init(PIN_OUT_HVPULSE);
    gpio_set_dir(PIN_OUT_HVPULSE, GPIO_OUT);
    // No pullups & pulldowns
    gpio_set_pulls(PIN_OUT_HVPULSE, false, false);
    // Adjust slew-rate & drive strength. 
    gpio_set_drive_strength(PIN_OUT_HVPULSE, GPIO_DRIVE_STRENGTH_12MA);
    gpio_set_slew_rate(PIN_OUT_HVPULSE, GPIO_SLEW_RATE_FAST);
    gpio_put(PIN_OUT_HVPULSE, false);
}

void picoemp_configure_pulse_external() {
    // Configure pulse input
    gpio_init(PIN_OUT_HVPULSE);
    gpio_set_dir(PIN_OUT_HVPULSE, GPIO_IN);
    // No pullups & pulldowns
    gpio_set_pulls(PIN_OUT_HVPULSE, false, false);
}

void picoemp_init() {
    // Initialize LED GPIOs
    gpio_init(PIN_LED_HV);
    gpio_init(PIN_LED_STATUS);
    gpio_init(PIN_LED_CHARGE_ON);
    gpio_set_dir(PIN_LED_HV, GPIO_OUT);
    gpio_set_dir(PIN_LED_STATUS, GPIO_OUT);
    gpio_set_dir(PIN_LED_CHARGE_ON, GPIO_OUT);
    // Enable status LED
    gpio_put(PIN_LED_STATUS, true);

    // Initialize button GPIOs
    gpio_init(PIN_BTN_ARM);
    gpio_init(PIN_BTN_PULSE);
    gpio_set_dir(PIN_BTN_ARM, GPIO_IN);
    gpio_set_dir(PIN_BTN_PULSE, GPIO_IN);
    // ARM is active high, PULSE is active low
    // Enable ARM pulldown
    gpio_set_pulls(PIN_BTN_ARM, false, true);
    // Enable PULSE pullup
    gpio_set_pulls(PIN_BTN_PULSE, true, false);
    // Invert PULSE input so we can read ARM & PULSE both as active-high
    gpio_set_inover(PIN_BTN_PULSE, GPIO_OVERRIDE_INVERT);


    // Charge-detection coming from HV side
    gpio_init(PIN_IN_CHARGED);
    gpio_set_dir(PIN_IN_CHARGED, GPIO_IN);
    gpio_set_pulls(PIN_IN_CHARGED, false, false);
    // Charge is active-low, so we invert it to make the code seem
    // more logical
    gpio_set_inover(PIN_IN_CHARGED, GPIO_OVERRIDE_INVERT);

    // Configure pulse output
    picoemp_configure_pulse_output();

    // Configure PWM pin
    picoemp_disable_pwm();
}

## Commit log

2021-12-09 Add schematic
2021-12-10 Add shield
    [picoempshield-1551BTRD-top.f3d, picoempshield-1551BTRD-top.stl]
2021-12-10 Fix missing symbol in schematic
2021-12-17 Add gerbers + updated sch
    [chipshouter-pico.GBL, chipshouter-pico.GBO, chipshouter-pico.GBP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]
2021-12-17 Add assembly details
2021-12-21 Add BOM stuff
2021-12-21 Minor BOM fixes
2021-12-21 Minor bom edits
2021-12-21 More bom details
2021-12-21 Add bom split
2021-12-21 I got a fever, and the only prescription is MORE BOM
2021-12-21 Add example of milling output from Bantam
2021-12-23 Add BOM (xls, better format?)
    [BOM for ChipShouter-PicoEMP.xls]
2021-12-26 Add schematic as PNG (useful for documentation markdown files)
2022-01-07 Fix BOM C1/C2, add D2 description fix #6
    [BOM for ChipShouter-PicoEMP.xls]
2022-01-29 Bugfix firmware fast_trigger mode and added external_hvp mode
    [main.c, picoemp.c]
2022-05-02 add configurable duty_frac and pulse_time; add single character serial shortcuts; toggle command for gp1
    [main.c, picoemp.c]
2022-05-31 Add altium source
    [ChipShouter-Pico.PrjPcb, chipshouter-pico-hv.SchDoc, chipshouter-pico-mcu.SchDoc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]
2023-06-21 Add 2 probe pictures
2023-06-21 Add 2 examples of probes
2024-06-24 Fix pulse_power print

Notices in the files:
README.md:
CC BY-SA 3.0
